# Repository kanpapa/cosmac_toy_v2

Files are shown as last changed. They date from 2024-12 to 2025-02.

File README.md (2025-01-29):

# COSMAC Toy Computer Version 2

[COSMAC Toy Computer](https://github.com/kanpapa/cosmac_toy)は「トラ技別冊 つくるシリーズ7 手作りコンピュータ入門」（1981年5月初版）を参考にして、COSMAC CPUボードやプログラムローダーや実験回路をコンパクトな基板にまとめて製作したものです。  
ROMは搭載されておらず、トグルスイッチでRAMにプログラムを書き込んで実行できます。  
16進キーボードを使ったことはあるけど、トグルスイッチを使ってプログラムを動かしてみたいという方の願いを叶えようという思いで作られたシンプルなボードです。モニタプログラムなどの助けを借りずに、トグルスイッチでメモリを直接書き換えてプログラムを実行するといった一連の操作を体験できます。

最初に製作したCOSMAC TOYは1980年代の当時の環境に近づけるべく可能な限り書籍を忠実に再現することを第一に製作しましたので、やや入手が容易ではないパーツも含まれていました。  
このため、実機を使って[COSMACマイコン](https://kanpapa.com/cosmac/cosmac-cpu)の基本的な動きとトグルスイッチによるブートストラップを容易に体験いただけるようにVersion 2として見直しを行いました。

さらに高度なプログラミングを行いたい場合は、モニタが搭載された[SBC1802](https://vintagechips.wordpress.com/2021/04/13/sbc1802fixed/)や[MemberShip Card](https://www.sunrise-ev.com/1802.htm)などの利用をおすすめします。

## Version 2での変更点

* CPUボードとローダーボードを1枚の基板にまとめ、さらに製作を容易にしました。
* メモリを書き込み禁止にするトグルスイッチを追加することで、メモリ内容の読み出しや正しく手順を踏めばメモリの修正も行えるようになりました。
* 600milのS-RAMを使用できるようにしました。これにより600milの6264ALPやDIP変換基板に実装したフラットパッケージのS-RAMも使用できます。
* COSMAC CPUの全ピンにアクセスできるようにピンソケット用のパターンを併設しました。
* Q出力がLEDでモニタできるようになりました。基板単体でQ出力の確認ができます。
* COSMAC CPUとS-RAMを除きすべて秋月電子さんで購入できるパーツとしました。
* USB-C電源コネクタを追加しました。(Rev.0.3)
* 入力トグルスイッチと出力LEDにおいて上位4ビットと下位4ビットの間隔を少し空けました。(Rev.0.3)

## スペック

* CPU: COSMAC CDP1802
* RAM: 256byte
* ROM: 無し
* CLOCK: 約400kHz
* I/O: バスLED, Q-LED, バス設定トグルスイッチ, モード設定トグルスイッチ
* 電源: 5V 標準DCジャック(センタープラス)、USB-C電源(Rev.0.3)
* メモリバックアップバッテリー: CR2032 3V
* サイズ: 95mmX72mm
* 重さ: 約89g（全パーツ実装時）

## 外観
Rev.0.3  
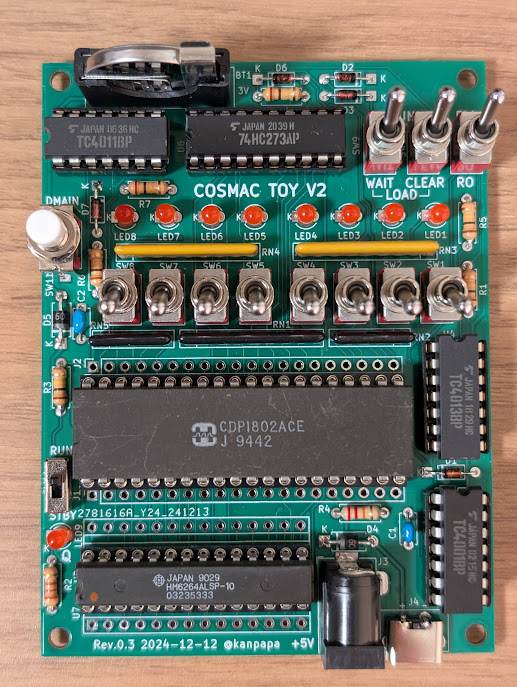
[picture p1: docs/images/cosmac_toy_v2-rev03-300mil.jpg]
rev03
  
[Rev.0.2](/docs/images/cosmac_toy_v2-rev02-600mil.jpg)  
[Rev.0.1](/docs/images/cosmac_toy_v2-rev01-prototype.jpg)  

## 特徴

* 入手が容易なパーツを使い、回路を極力簡素化することで必要なパーツ数を減らしています。専用基板も表面実装パーツは使用せずに製作しやすくしています。
* トグルスイッチで直接メモリに書き込むため、ROMライタなどの開発ツールは不要です。
* COSMAC CPUの全ピンにアクセスできるようにピンソケットを併設しています。CPUバスやQ出力やEF1~4入力などのアクセスはここから行ってください。
* メモリは6264を使用していますが、実際に使えるのは256バイトだけです。これはトグルスイッチで正確に手入力できるのは256バイトが限界と思われるため、アドレスバスを簡略化したためです。
* S-RAMは簡易的なバッテリバックアップが行えます。SW11をSTBYにするとメモリをスタンバイ状態にし、バッテリーで内容が保持されます。
* 8つのLEDはバスの信号をラッチしてバスの状態を表示することができます。
* 右上の3つのトグルスイッチで、CPUの動作モードを設定したあとに、DMA INにつながっているプッシュスイッチを押すことで、トグルスイッチで設定した値をメモリに書き込むことができます。ROにすることでメモリに書き込まずメモリの状態を確認することもできます。
* トグルスイッチはバスの信号を直接0/1に設定します。通常はバスバッファを介しますが、シンプルな回路にするために省略しています。
* Q出力はLEDが接続されています。  
* COSMAC CPUのクロックはCR発振なのでCRの値を変えることで周波数を調整できます。
* 本基板のサイズは秋月電子のB基板に合わせました。

## 基本的な操作方法

* [Quick start guide](/docs/cosmac_toy_v2_quick_start_guide.pdf)も合わせてご覧ください。

    UP    トグルスイッチを上側に倒します  
    DOWN  トグルスイッチを下側に倒します  
     ↓  　トグルスイッチの状態をそのまま維持します。（変更しない）  
     ー   トグルスイッチの状態は任意です。（上側でも下側でも良い）  

1. メモリ書き込み

    |Step|SW9|SW10|SW12|操作内容|
    |---|----|---|----|----|
    |1	|UP|DOWN|-|CPUを初期状態(P, X, R(0)を0)にする(RESETモード)|	
    |2	|↓|↓|UP|メモリ書き込み許可|
    |3	|DOWN|↓|↓|メモリロード状態にする(LOADモード)|
    |4	|| | |トグルスイッチでメモリに書き込む値を設定→DMAINを押す（これを繰り返す） |

1. メモリ読み出し
    |Step|SW9|SW10|SW12|操作内容|
    |---|---|----|----|----|
    |1	|UP|DOWN|-|CPUを初期状態にする(RESETモード)|
    |2  |↓|↓|DOWN|メモリ書き込み禁止|
	|3  |DOWN|↓|↓|メモリロード状態にする(LOADモード)|	
	|4  | | | |DMAINボタンを押すとメモリの内容が表示される（これを繰り返す）|		

1. プログラム実行
    |Step|SW9|SW10|SW12|操作内容|
    |---|----|---|----|----|
    |1|UP|DOWN|-|CPUを初期状態にする(RESETモード)|
    |2|↓|↓|UP|メモリ書き込み許可(メモリに書き込む処理があるプログラムの場合)|	
	|3|↓|UP|↓|プログラム実行状態にする(RUNモード)|

1. プログラム一時停止
    |Step|SW9|SW10|SW12|操作内容|
    |---|---|---|---|---|
	|1|DOWN|UP|-|プログラム実行を一時停止する(PAUSEモード)|
	|2|UP|↓|- |プログラム実行状態にする(RUNモード)|

1. メモリバックアップ状態〜通常状態への切替
    |Step|SW9|SW10|SW12|SW11|操作内容|
    |---|---|---|---|---|---|
    |1|DOWN|UP|-|RUN|プログラムを一時停止する(PAUSEモード)|
    |2|↓|↓|DOWN|↓|メモリ書き込み禁止|
    |3|↓|↓|↓|STBY|RAMをスタンバイモードにする|
    |4|↓|↓|↓|↓|電源を切断|
    |5|DOWN|UP|DOWN|STBY|PAUSEモード+メモリ書き込み禁止になっていることを確認|
    |6|↓|↓|↓|↓|電源を投入|
    |7|↓|↓|↓|RUN|RAMをノーマルモードにする|

※メモリバックアップを行わない場合はリチウム電池は抜いておいてください。電源が供給されない状態でSW11がRUNのままだと放電してしまいます。

## ハードウェア

- [回路図](/schematics/)
- [部品表](/bom/)
- [KiCadデータ](/kicad/)
- [ガーバーデータ](/gerber/)
- [組み立て手順例](/docs/Assembly_instruction/)
- 組み立て時の注意事項  
    - 部品表に記載されているLEDと異なるLEDを使用する場合は、RN3 2.2KΩの集合抵抗では眩しすぎる場合もありますので、丸ピンソケットを利用して集合抵抗を交換調整できるようにしておくことをお勧めします。

## ソフトウェア
 
- [サンプルアプリケーション](/programs/)

## 補足情報

- [COSMAC研究会](https://kanpapa.com/cosmac/)に関連記事をまとめています。

## 参考・引用文献

- トランジスタ技術別冊 つくるシリーズ７ 手作りコンピュータ入門 CQ出版社, 1981
- [KiCad 8 入門実習テキスト『KiCad Basics for 8.0』Kosaka.Lab.出版掛](https://kosakalab.booth.pm/items/5554691)
- [intersil CDP1802AC/3データシート](https://www.renesas.com/jp/ja/www/doc/datasheet/cdp1802ac-3.pdf)
- [SB-Assembler](https://www.sbprojects.net/sbasm/)
- [COSMAC ELF - RCA CDP1802 Computing](http://www.cosmacelf.com/)
- [Compute II Issue 3: The 1802 Instruction Set](https://www.atarimagazines.com/computeii/issue3/page52.php)
- [The 1802 Membership Card](http://www.sunrise-ev.com/1802.htm)

## 利用上の注意

本サイトに掲載している回路、技術、プログラムなどは無保証です。  
これらの利用によって発生したトラブルには責任を負いかねます。自己責任にてご利用ください。  
KiCADデータおよびガーバーデータはCC BY-SA 4.0 (Copyright (C) 2024 Kazuhiro Ouchi)です。  
サンプルプログラムはMITライセンスです。

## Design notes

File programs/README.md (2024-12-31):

# COSMAC TOY Computer Sample program

サンプルプログラムのアセンブラソースとSB-Assemblerでアセンブルしたリストです。  
こちらを参考にしてプログラムの入力や改良をしてください。

## サンプルプログラム

* [パルス信号を作る](01_osc1/README.md)
    * [01_osc1](01_osc1) - 動作確認用。Q出力の0,1を繰り返します。Q出力のLEDは超高速点滅なので点灯したままに見えます。オシロであれば信号を確認できます。
* [カウンタプログラム1](02_counter1/README.md)
    * [02_counter1](02_counter1) - 加算しているカウンタの値をLEDに表示し続けます。速すぎて最上位ビットのLEDがチラチラするだけで他のLEDは点灯状態に見えます。
* [カウンタプログラム2](03_counter2/README.md)
    * [03_counter2](03_counter2) - 加算しているカウンタの値をLEDに表示し続ける低速表示版です。これぐらいでようやくカウントの様子が見えます。
* [加算プログラム](04_add1/README.md)
    * [04_add1](04_add1) - トグルスイッチで設定した値に6を加算した数値をLEDに表示します。
* [押しボタンスイッチでQ出力を制御](05_sw1/README.md)
    * [05_sw1](05_sw1) - EF1に接続したスイッチを押すとQ-LEDが消灯し、離すとQ-LEDが点灯します。
* [Q LEDを点滅させる](06_blink1/README.md)
    * [06_blink1](06_blink1) - Q LEDが一定時間間隔で点滅します。いわゆるLチカです。
* [POVを試してみる](07_pov1/README.md)
    * [07_pov](07_pov1) - POV(Persistent Of Vision)によるメッセージ表示です。もう少しチューニングできると思います。
* [シリアルバイナリローダー](08_binloader1/README.md)
    * [08_binloader1](08_binloader1) - USBシリアル変換モジュールを接続して入力されたシリアルデータをLEDに表示しながらメモリに書き込みます。

## Requirement

This source file can be assembled using SB-Assembler 3.
* [SB-Projects - SB-Assembler](https://www.sbprojects.net/sbasm/)

## License

This software is released under the [MIT license](https://en.wikipedia.org/wiki/MIT_License).

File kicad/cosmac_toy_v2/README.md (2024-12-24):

# COSMAC TOY V2 KiCad project

COSMAC TOY V2の基板のKiCADデータです。

以下に公開されているフットプリントを使用させていただきました。

* USB Type-Cコネクター 電源供給用	A295-CTRPB-1:A295-CTRPB-1  
https://github.com/21km43/A295-CTRPB-1_KiCAD  
Copyright (c) 2023 Koki Mizumoto

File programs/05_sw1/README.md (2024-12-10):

# 押しボタンスイッチでQ出力を制御

## 概要
EF1～EF4（4フラグ）の使用例です。  
EF1～EF4入力により、外部機器からのステータス情報をプロセッサに転送できます。
これらの入力レベルは、条件分岐命令でテストできます。

ここではEF1端子に押しボタンスイッチを接続し、スイッチを押した場合はEF1端子がHIGH、押していないときはEF1端子がLOWとなるようにしています。  
プログラムでEF1端子がHIGH(=5V)なのかLOW(=0V)なのかで処理を分岐し、Q出力を1にセットするもしくは0にリセットする処理を行います。

## 使用する命令

|INSTRUCTION|MNEMONIC|OP CODE|OPERATION|
|---|---|---|---|
|SHORT BRANCH IF EF1 = 1 (EF1 = VSS)|B1|34|IF EF1 = 1, M(R(P)) → R(P).0, ELSE R(P) + 1 → R(P)|
|RESET Q|REQ|7A|0 → Q|
|SHORT BRANCH|BR|30|M(R(P)) → R(P).0|
|SET Q|SEQ|7B|1 → Q|

## サンプルコード

```
0000-34 05    START:  B1      L1                  ; ~EF1 = 1(VSS) だったら L1にジャンプ
0002-7A               REQ                         ; Q出力を0にする(LED消灯)
0003-30 00            BR      START               ; 0000番地にジャンプ
0005-7B       L1:     SEQ                         ; Q出力を1にする(LED点灯)
0006-30 00            BR      START               ; 0000番地にジャンプ
```

## 回路図

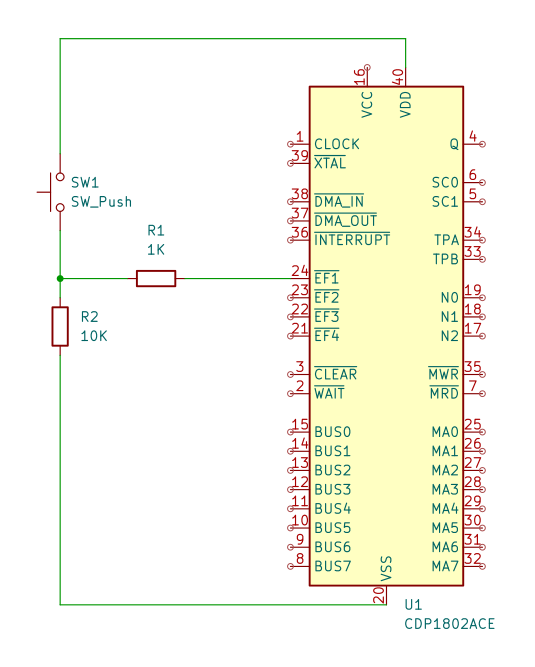
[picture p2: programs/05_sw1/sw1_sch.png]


## 実行結果
手元にあったDFROBOT社の[Gravity: Digital Push Button (Yellow)](https://www.dfrobot.com/product-73.html)を使用しています。  
画像をクリックすると動画が再生されます。

sw1 video (https://www.youtube.com/watch?v=XKFlwYPNNAE)

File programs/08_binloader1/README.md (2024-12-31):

# Serial Binary loader for COSMAC TOY V2

[プログラム05 押しボタンスイッチ](/programs/05_sw1/README.md)ではEF1端子の入力信号を読み取ってQ-LEDを点灯させました。  
これを応用してシリアルデータ信号をEF端子に入力することで、データ転送ができるのではないでしょうか。  
実際にそのような使いかたを行って、シリアル通信を使ってバイナリデータをメモリにロードすることができます。

オリジナルは1802 MemberShip Card用のプログラムですが、これをCOSMAC TOY V2でも動作するように修正しました。

* 参考サイト
    [Serial Binary loader for 1802 Membership Card](https://www.retrotechnology.com/memship/mship_binloader.html)
* 参考ソース
    [Here's Jonathan Mordosky's original binary loader code](https://www.retrotechnology.com/memship/binldr_m.asm)

## 回路図

COSMAC TOY V2とUSBシリアル変換モジュールを接続しPCと接続します。IOの電圧は5Vのものを使用してください。  
私は秋月電子の[FT-232RQ USBシリアル変換モジュール](https://akizukidenshi.com/catalog/g/g111007/)を使用しました。

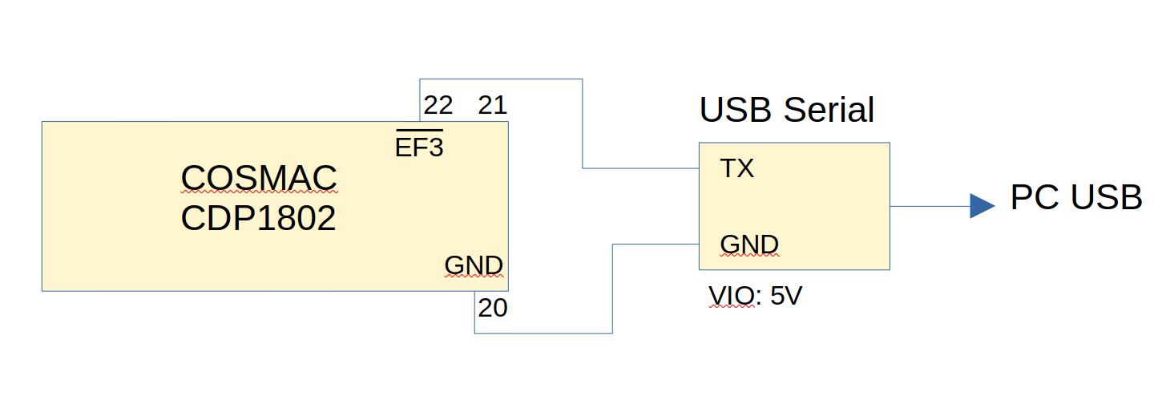
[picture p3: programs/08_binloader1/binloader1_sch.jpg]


実際にUSBシリアル変換モジュールに接続している様子です。

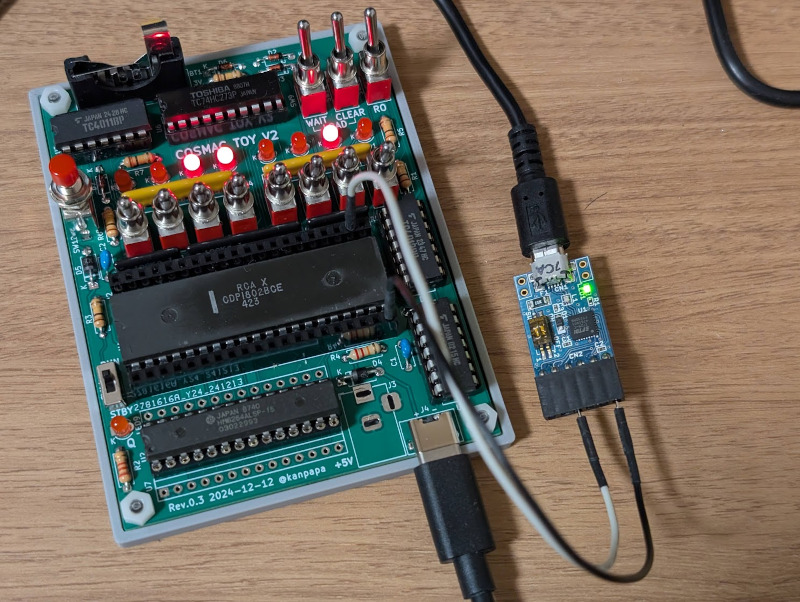
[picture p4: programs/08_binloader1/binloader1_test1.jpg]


## 実際のシリアル信号

上記の回路図でEF3端子にどのような信号が流れるのかをロジックアナライザで確認しました。このシリアルデータはスペースコード(0x20)です。



最初の緑色の点がスタートビットです。  
その後、データの下位ビットから上位ビットに向けてデータのビットが８個並びます。  
最後の赤色の点がストップビットです。  
プログラムではこの信号をEF3端子で読み取って、ソフトウェアでシリアルデータをデコードしてメモリにストアします。

## ソースコード

修正したソースコードのアセンブル結果は以下のようになります。シリアル信号を見ながら追ってみてください。  
COSMAC TOY V2用に修正した箇所は以下の通りです。
- メモリが0000-00FFまでしか使えないのでロードアドレスは0040-としました。
- オリジナルのソースコードでは信号が反転していたので、EF3のチェック部分を反転しました。（B3をBN3に、BN3をB3に入れ替えています。）

最初にスペースコードを入力することで、1ビットの時間をカウントしています。このカウント値を使用したタイミングで読み取ることでシリアルデータのビットに追従します。COSMAC TOY V2はクロックが400KHzなので高速通信は難しいですが、300bpsは問題なく動作しました。

※ソースコードは暫定版です。コメントなど整理した上で更新予定です。
```
SB-Cross Assembler version 3.03.10
Please visit www.sbprojects.net for a complete description.

Assembling....

Pass one
Loaded 1802 overlay version 3.01.01

Pass two
0000-                  1        ; 1802 Membership Card .bin loader by Jonathan Mordosky
0000-                  2        ; Edited by Lee Hart Oct 29 2015, JOnathan Mordosky Nov 3 2015
0000-                  3        ;
0000-                  4        ; first, here is the original by Jonathan Mordosky in cosmacelf Oct 2015
0000-                  5        ; Loads binary file starting at address XX00, Where XX is any page in memory above 00
0000-                  6        ; For 1802 Membership Card, serial port configured as Normal (not inverting)
0000-                  7        ; Tested at 300 baud 8N1. Should work at slightly higher baud rates
0000-                  8        ;
0000-                  9        ; To Use: Toggle in program as usual.
0000-                 10        ; Start up and configure communications program on host computer.
0000-                 11        ; On 1802MC, make sure write protect is off. Flip switch to Clear, then Run.
0000-                 12        ; Hit <Space> exactly once on host computer, watching that the output LEDs do not change.
0000-                 13        ; On newer revision boards, the green LED will blink as the space character is received.
0000-                 14        ; Send BIN file as ASCII from host computer. Make sure program settings don't strip the 8th bit.
0000-                 15        ; Output LEDs should now change and show the data as it is received.
0000-                 16        ;
0000-                 17        ; When blinking stops, verify that the LEDs match the last byte of the program.
0000-                 18        ; Toggle in a long jump instruction to start of program (0xC0 0xXX 0x00) and run.
0000-                 19        ; If unsuccessful, check com settings and try again.
0000-                 20
0000-                 21        ; Binary loader for COSMAC TOY V2 by Kazuhiro Ouchi
0000-                 22        ; Edited by Kazuhiro Ouchi Dec 31 2024
0000-                 23        ; This source program can be assembled with the SB assembler.
0000-                 24
0000-                 25        ; hex listing for COSMAC TOY V2
0000-                 26
0000-                 27        ;0000   F8 00 B2 F8 40 A2 E2 F8
0000-                 28        ;0008   00 3E 09 36 0B FC 01 3E
0000-                 29        ;0010   0D FF 04 B3 36 14 F8 09
0000-                 30        ;0018   A3 3E 19 93 F6 38 93 FF
0000-                 31        ;0020   01 3A 1F 02 F6 36 29 F9
0000-                 32        ;0028   80 52 23 83 3A 1E 61 30
0000-                 33        ;0030   14
0000-                 34
0000-                 35                .CR 1802
0000-                 36                .OR 0000H       ;initialization　　　　　　　　 初期化
0000-                 37        Page    .eq     00      ; desired page destination      バイナリをロードするページ先。COSMAC TOYは256byteメモリなので00で良い
0000-                 38        ;
0000-F8 00            39 (   2)         LDI Page        ;Set destination starting address   デスティネーション開始アドレスの設定
0002-B2               40 (   2)         PHI 2           ;R2 points to destination           R2 はデスティネーションを指す。
0003-                 41        ;       GHI 0           ;  LSB of destination is 00
0003-F8 40            42 (   2)         LDI $40         ;  LSB of destination is 40  COSMAC TOYの場合はデスティネーションの下位バイトは40とする。
0005-A2               43 (   2)         PLO 2           ;  (assumes this program is at 00XX)  ロードするプログラムは00XXにあると仮定する。
0006-E2               44 (   2)         SEX 2
0007-F8 00            45 (   2)         LDI 0           ; Dレジスタを$40にしてしまったので0を設定しておく。(Timeで使うから)
0009-                 46
0009-3E 09            47 (   2) LoopA   BN3 LoopA       ;スタートビットを待つ。EF3がHIGHの場合はループ。B3がLOWになったら次のステップへ
000B-                 48
000B-36 0B            49 (   2) LoopB   B3 LoopB        ;ASCIIコードのスペースのD5=1のデータビット(EF3がHIGH)を待つ。（データはLSBファーストで送信される）
000D-                 50                                                ;time Data bit D5
000D-                 51                                                ;  Dレジスタは0に初期化済
000D-FC 01            52 (   2) Time    ADI 1           ;  D=D+1 for each loop   Dを1加算するループ
000F-3E 0D            53 (   2)         BN3 Time        ;  ...until end of bit   データビット終了(EF3=LOWになる)までループで加算し続ける。データビットが終了したら次のステップへ
0011-                 54                                        ;each loop is 2 instructions,
0011-                 55                                        ;so Delay x 2 = number of instructions per bit
0011-FF 04            56 (   2)         SMI 4           ;Subtract 4 extra instructions
0013-B3               57 (   2)         PHI 3           ;Store Delay Constant in R3.1
0014-                 58
0014-                 59        ;       so (Delay+4) x 2 = # of instructions in one bit time
0014-                 60
0014-                 61                                                ;OK, we're ready to receive data
0014-36 14            62 (   2) Main    B3 Main         ;ストップビット(EF3=HIGH)を待つ
0016-F8 09            63 (   2)         LDI 9           ;R3.0 = #bits = 9
0018-A3               64 (   2)         PLO 3
0019-3E 19            65 (   2) LoopC   BN3 LoopC       ;スタートビット(EF3=LOW)を待つ
001B-93               66 (   2)         GHI 3           ;Delay 1/2 bit time
001C-F6               67 (   2)         SHR             ;  to move to middle of bit
001D-38               68 (   2)         SKP             ;
001E-93               69 (   2) NextBit GHI 3           ;Delay one bit time
001F-                 70
001F-FF 01            71 (   2) Delay   SMI 001H
0021-3A 1F            72 (   2)         BNZ Delay
0023-                 73
0023-02               74 (   2)         LDN 2           ;Get bits received so far...
0024-F6               75 (   2)         SHR                 ;  Shift right, and set most.sig.bit=0
0025-36 29            76 (   2)         B3 Zero             ;  if serial input=1 (i.e. EF3 pin is low)　シリアルデータビットが0（EF3がLow）の場合は分岐する
0027-F9 80            77 (   2)         ORI 080H        ;    then set most.sig.bit=1 シリアルデータビットが1の場合はORでビットを立てる
0029-52               78 (   2) Zero    STR 2           ;Store Data  R2は転送先アドレスを指す。そこにデータをストアする
002A-23               79 (   2)         DEC 3           ;Count out bits　処理したビットをカウント
002B-83               80 (   2)         GLO 3
002C-3A 1E            81 (   2)         BNZ NextBit     ;Loop until byte Finished
002E-                 82        ;       OUT 4           ;Show Data and INC Pointer
002E-61               83 (   2)         OUT 1           ;受信したデータをLEDに表示。COSMAC TOY V2の場合はOUT1なので変更しました。
002F-30 14            84 (   2)         BR  Main        ;Get next byte
0031-                 85
0031-                 86                .EN

0 Errors found during assembly.
0 Warnings found during assembly.
```

## 実行方法
1. 以下のシリアルローダープログラムをトグルスイッチで入力します。49バイトですので頑張って入力しましょう。
    ```
    0000   F8 00 B2 F8 40 A2 E2 F8
    0008   00 3E 09 36 0B FC 01 3E
    0010   0D FF 04 B3 36 14 F8 09
    0018   A3 3E 19 93 F6 38 93 FF
    0020   01 3A 1F 02 F6 36 29 F9
    0028   80 52 23 83 3A 1E 61 30
    0030   14
    ```
1. USBシリアル変換モジュールをCOSMAC TOY V2に接続します。
1. リセットしてシリアルローダープログラムを実行します。メモリは書き込み可能な状態にしてください。
1. PCでシリアルターミナルを起動します。通信速度は300bpsで、データ形式は8N1（データ8ビット、ストップ１ビット、パリティ無し）に設定してください。
1. シリアルターミナルから最初にスペースキーを１回押下します。これでプログラムが通信速度を設定します。
1. その後バイナリデータをPCのシリアルターミナルから送信すると、その内容が0040以降に書き込まれます。
1. バイナリデータを送信し終わったら、最後のデータの内容とLEDの表示が一致しているはずです。ここでプログラムを停止してください。(WAITスイッチを上側に倒す)
1. メモリの書き込みを禁止して、LOADモードにして、0040以降にアップロードしたバイナリデータが書かれているかを確認してください。

バイナリデータの代わりに、キーボードから文字を入力すればそのASCIIコードが0040以降に書き込まれます。文字を入力するたびにLEDがその文字のASCIIコードに変化することが確認できます。

## 実行結果
PCのシリアルターミナルで数字のキーを押すとASCIIコードの0x30-0x39がLEDに表示されます。  
クリックすると動画が表示されます。  
binloader1-1 video (https://www.youtube.com/watch?v=f7oefC-dY0M)

PCのシリアルターミナルで適当にキーボードを入力すると、入力した文字のASCIIコードがLEDに表示されます。  
クリックすると動画が表示されます。  
 binloader1-2 video (https://www.youtube.com/watch?v=1_WPMiToYoo)

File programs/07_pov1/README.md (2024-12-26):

# POVを試してみる

## 概要
いわゆるPOV(Persistent Of Vision)です。目の残像を利用してLEDでメッセージを表示するものです。　  
COSMAC TOY V2では8個のLEDが使えますので、このLEDにビットマップデータの1列毎に一定時間表示するようにしておきます。この状態でCOSMAC TOY V2基板を横に振ることでうまくいけばメッセージが表示されているように見えます。  
個人差や照明環境もありますので、うまく見えない場合は7行目のLDI 60の値を調整してください。  
表示するビットマップデータを入れ替えることもできます。ビットマップのデータ数を4行目のLDI 27で設定していますので、ビットマップデータの長さに合わせて調整してください。  
ビットマップデータの値でLEDを表示するためにOUT 1命令を使用していますが、この命令は自動的にインデックスレジスタを加算してくれますので、今回のような連続したデータの出力は容易に行えることがわかります。

## 使用する命令
|INSTRUCTION|MNEMONIC|OP CODE|OPERATION|
|---|---|---|---|
|LOAD IMMEDIATE|LDI|F8|M(R(P)) → D; R(P) + 1 → R(P)|
|PUT LOW REG N|PLO|AN|D → R(N).0|
|SET X|SEX|EN|N→X|
|OUTPUT 1|OUT 1|61|M(R(X)) → BUS; R(X) + 1 → R(X); N LINES = 1|
|DECREMENT REG N|DEC|2N|R(N) - 1 → R(N)|
|GET LOW REG N|GLO|8N|R(N).0 → D|
|SHORT BRANCH IF D NOT 0|BNZ|3A|IF D NOT 0, M(R(P)) → R(P).0, ELSE R(P) + 1 → R(P)|
|SHORT BRANCH|BR|30|M(R(P)) → R(P).0|

## サンプルコード

```
0000-                  1        *
0000-                  2        * POV program 1 for COSMAC TOY V2
0000-                  3        * SB-Assembler
0000-                  4        *
0000-                  5                .CR     1802    ;To load the 1802 cross overlay
0000-                  6                .OR     $0000
0000-                  7        *
0000-                  8        * R3 BITMAPデータを指すインデックスレジスタ
0000-                  9        * R4 BITMAPデータの個数カウンタ
0000-                 10        * R5 ウェイトカウンタ
0000-                 11        *
0000-F8 15            12 (   2) START   LDI     #BITMAP ; DレジスタにBITMAPデータの先頭アドレスを設定
0002-A3               13 (   2)         PLO     3       ; R3にBITMAPのアドレスを設定
0003-E3               14 (   2)         SEX     3       ; R3をインデックスレジスタに設定
0004-F8 1B            15 (   2)         LDI     27      ; DレジスタにBITMAPデータの個数である27を設定する
0006-A4               16 (   2)         PLO     4       ; R4にBITMAPデータカウンタの初期値を設定する
0007-61               17 (   2) LOOP1   OUT     1       ; BITMAPのデータでLEDを表示する。R3は自動インクリメントされる。BUS <- M(R(3)); R(3)++
0008-F8 3C            18 (   2)         LDI     60      ; ウェイトカウンタの初期値←ここは調整要
000A-A5               19 (   2)         PLO     5       ; R5をウェイトカウンタとしてDレジスタから初期値を設定する
000B-25               20 (   2) LOOP2   DEC     5       ; ウェイトカウンタを1減らす。
000C-85               21 (   2)         GLO     5       ; Dレジスタにウェイトカウンタをセット
000D-3A 0B            22 (   2)         BNZ     LOOP2   ; Dレジスタが0でなかったらLOOP2へ
000F-24               23 (   2)         DEC     4       ; BITMAPカウンタを１減らす
0010-84               24 (   2)         GLO     4       ; DレジスタにBITMAPデータカウンタの値をセット
0011-3A 07            25 (   2)         BNZ     LOOP1   ; Dレジスタが0でなかったらLOOP1へ
0013-30 00            26 (   2)         BR      START   ; BITMAPのデータを表示し終えたので、最初から繰り返し
0015-                 27        *
0015-                 28        * BITMAP DATA "HELLO" 27byte
0015-                 29        *
0015-FE               30        BITMAP  .DB     0b11111110      ; H
0016-10               31                .DB     0b00010000
0017-10               32                .DB     0b00010000
0018-10               33                .DB     0b00010000
0019-FE               34                .DB     0b11111110
001A-00               35                .DB     0b00000000
001B-                 36
001B-FE               37                .DB     0b11111110      ; E
001C-92               38                .DB     0b10010010
001D-92               39                .DB     0b10010010
001E-92               40                .DB     0b10010010
001F-00               41                .DB     0b00000000
0020-                 42
0020-FE               43                .DB     0b11111110      ; L
0021-80               44                .DB     0b10000000
0022-80               45                .DB     0b10000000
0023-80               46                .DB     0b10000000
0024-00               47                .DB     0b00000000
0025-                 48
0025-FE               49                .DB     0b11111110      ; L
0026-80               50                .DB     0b10000000
0027-80               51                .DB     0b10000000
0028-80               52                .DB     0b10000000
0029-00               53                .DB     0b00000000
002A-                 54
002A-FE               55                .DB     0b11111110      ; O
002B-82               56                .DB     0b10000010
002C-82               57                .DB     0b10000010
002D-82               58                .DB     0b10000010
002E-FE               59                .DB     0b11111110
002F-00               60                .DB     0b00000000
0030-                 61
0030-                 62                .EN
```

## 実行結果
このプログラムを実行するとLEDがチラチラするだけで、正常に動作しているのかわかりません。  
画像をクリックすると動画が再生されます。  
blink1 video (https://www.youtube.com/watch?v=aNgpml-eRWY)

この状態でCOSMAC TOY V2基板を手に持ち横に振るとかろうじてメッセージが見えます。（心の目で見てください・・・）  
画像をクリックすると動画が再生されます。  
blink1 video (https://www.youtube.com/watch?v=d47GrqhgYpU)

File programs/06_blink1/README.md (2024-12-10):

# Q LEDを点滅させる

## 概要
Q LEDが一定時間間隔で点滅します。いわゆるLチカです。  
最初にアキュームレータである8ビットのDレジスタに$40を設定していますが、この値は点滅間隔の待ち時間のカウンタとして使用されるR4レジスタの上位バイトに代入されます。  
COSMACの汎用レジスタ(R0〜RF)は16bitですが、16bitの値を直接設定することができないため、Dレジスタを介して上位バイト、下位バイトに8bitずつ値を設定する必要があります。なおリセット直後は各レジスタの値は0となっていますので、R4の下位バイトの0設定は省略しています。  
R4レジスタを1減算したあとに、0になったかを確認していますが、この確認もDレジスタを使う必要があり、上位バイト、下位バイトをそれぞれ確認しています。  

このように何をやるにしてもこのDレジスタを経由して行うことが多いです。

## 使用する命令
|INSTRUCTION|MNEMONIC|OP CODE|OPERATION|
|---|---|---|---|
|LOAD IMMEDIATE|LDI|F8|M(R(P)) → D; R(P) + 1 → R(P)|
|PUT HIGH REG N|PHI|BN|D → R(N).1|
|LONG SKIP IF Q = 1|LSQ|CD|IF Q = 1, R(P) + 2 → R(P), ELSE CONTINUE|
|SET Q|SEQ|7B|1 → Q|
|SHORT SKIP|SKP|38|R(P) + 1 → R(P)|
|RESET Q|REQ|7A|0 → Q|
|DECREMENT REG N|DEC|2N|R(N) - 1 → R(N)|
|GET LOW REG N|GLO|8N|R(N).0 → D|
|GET HIGH REG N|GHI|9N|R(N).1 → D|
|SHORT BRANCH IF D NOT 0|BNZ|3A|IF D NOT 0, M(R(P)) → R(P).0, ELSE R(P) + 1 → R(P)|
|SHORT BRANCH|BR|30|M(R(P)) → R(P).0|

## サンプルコード

```
0000-F8 40    START:  LDI     #$40                ; Dレジスタに$40を入れる（点滅間隔のウェイトループ値）
0002-B4               PHI     4                   ; R4の上位バイトにDレジスタの値を代入する
0003-CD               LSQ                         ; Qが1だったら2バイトスキップする
0004-7B               SEQ                         ; Qを1にする
0005-38               SKP                         ; 次の命令を無条件でスキップする
0006-7A               REQ                         ; Qを0にする
0007-24       LOOP1:  DEC     4                   ; R4を1減算する
0008-84               GLO     4                   ; DレジスタにR4の下位バイトを代入する
0009-3A 07            BNZ     LOOP1               ; Dレジスタが0でなければLOOP1にジャンプ
000B-94               GHI     4                   ; DレジスタにR4の上位バイトを代入する
000C-3A 07            BNZ     LOOP1               ; Dレジスタが0でなければLOOP1にジャンプ
000E-30 00            BR      START               ; 0番地から繰り返し
```

## 実行結果
Q-LEDの点滅ができました。  
画像をクリックすると動画が再生されます。

blink1 video (https://www.youtube.com/watch?v=glT6MU6y57Q)

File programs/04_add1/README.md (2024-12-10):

# 加算プログラム

## 概要
トグルスイッチで設定した値に6を加算した数値をLEDに表示します。

## 使用する命令
|INSTRUCTION|MNEMONIC|OP CODE|OPERATION|
|---|---|---|---|
|LOAD IMMEDIATE|LDI|F8|M(R(P)) → D; R(P) + 1 → R(P)|
|PUT LOW REG N|PLO|AN|D → R(N).0|
|SET X|SEX|EN|N→X|
|INPUT 2|INP 2|6A|BUS → M(R(X)); BUS → D; N LINES = 2|
|ADD|ADD|F4|M(R(X)) + D → DF, D|
|STORE VIA N|STR|5N|D → M(R(N))|
|OUTPUT 1|OUT 1|61|M(R(X)) → BUS; R(X) + 1 → R(X); N LINES = 1|
|DECREMENT REG N|DEC|2N|R(N) - 1 → R(N)|
|SHORT BRANCH|BR|30|M(R(P)) → R(P).0|

## サンプルプログラム

```
0000-F8 0D  START LDI #IOR    IOレジスタのメモリアドレスをDレジスタに代入する
0002-A5           PLO 5       Dレジスタの内容をR5レジスタの下位8ビットに代入する。（R5レジスタはIOレジスタのメモリアドレスになる。）
0003-E5           SEX 5       5をインデックスレジスタXに代入する。
0004-6A     LOOP1 INP 2       BUSの内容をR(X)レジスタ（ここではR5レジスタ）が示すメモリに代入する。
0005-F8 06        LDI #$06    加算する値である6をDレジスタに代入する。
0007-F4           ADD         R(X)レジスタ（ここではR5レジスタ）が示すメモリの内容とDレジスタを加算する。
0008-55           STR 5       Dレジスタの内容をR5レジスタが示すメモリに代入する。
0009-61           OUT 1       R(X)レジスタ（ここではR5レジスタ）が示すメモリの内容をLEDに出力する。
000A-25           DEC 5       OUT命令でR5に1加算されるので、1減算して元に戻す。
000B-30 04        BR LOOP1    LOOP1にジャンプする。
000D-       *
000D-00     IOR   .DB 0       IO Register
```

## 動作確認
* このプログラムを動かして、トグルスイッチを00000000（10進数で0）にするとLEDの値は00000110（10進数で6）になります。
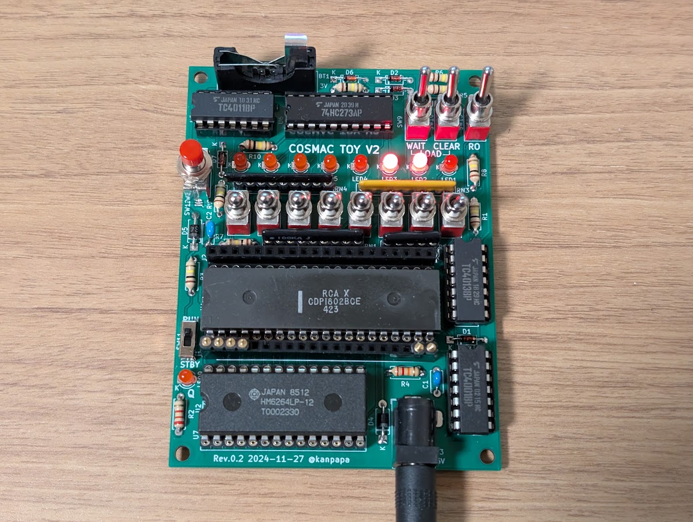
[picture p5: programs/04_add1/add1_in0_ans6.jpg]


* トグルスイッチを00000010（10進数で2）とすると、LEDの値は00001000（10進数で8）になります。
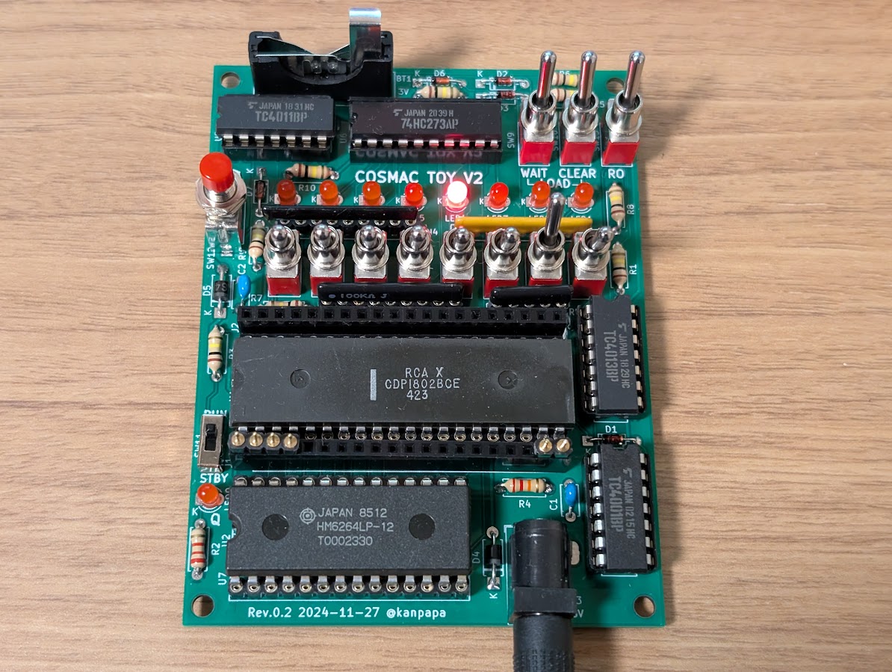
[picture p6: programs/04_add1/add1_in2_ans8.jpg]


* トグルスイッチを00000110（10進数で6）とすると、LEDの値は00001100（10進数で12）になります。
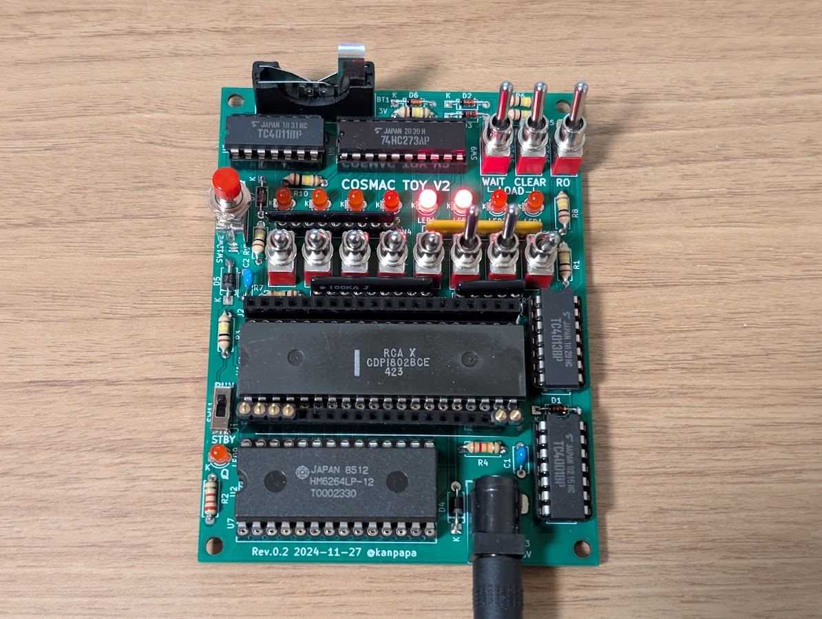
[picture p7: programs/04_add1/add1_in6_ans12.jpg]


* このようにいろいろな数値をトグルスイッチで設定して結果を確認してみてください。

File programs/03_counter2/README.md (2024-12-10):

# カウンタプログラム2

## 概要
R4レジスタをカウントアップしてその値をLEDに表示することを繰り返すものですが、カウンタプログラム1の命令を１つ変更するだけで、R4レジスタの下位8ビットの値をLEDに出力していたものが、上位8ビットの値をLEDに出力するようになります。この結果LEDの表示が256分の1の速度になります。

## 使用する命令
|INSTRUCTION|MNEMONIC|OP CODE|OPERATION|
|---|---|---|---|
|LOAD IMMEDIATE|LDI|F8|M(R(P)) → D; R(P) + 1 → R(P)|
|PUT LOW REG N|PLO|AN|D → R(N).0|
|SET X|SEX|EN|N→X|
|GET HIGH REG N|GHI|9N|R(N).1 → D|
|STORE VIA N|STR|5N|D → M(R(N))|
|OUTPUT 1|OUT 1|61|M(R(X)) → BUS; R(X) + 1 → R(X); N LINES = 1|
|DECREMENT REG N|DEC|2N|R(N) - 1 → R(N)|
|INCREMENT REG N|INC|1N|R(N) + 1 → R(N)|
|SHORT BRANCH|BR|30|M(R(P)) → R(P).0|

## サンプルプログラム
```
0000-F8 31   START LDI #$31    #$31をDレジスタに入れる
0002-A3            PLO 3       Dレジスタの内容をR3レジスタの下位8ビットに入れる
0003-E3            SEX 3       3をインデックスレジスタXに入れる
0004-94      LOOP1 GHI 4       R4レジスタの上位8ビットをDレジスタに入れる
0005-53            STR 3       Dレジスタの内容をR3レジスタが示すメモリに代入する。
0006-61            OUT 1       R(X)（ここではR3）レジスタが示すメモリの内容をBUSに出力する。
0007-23            DEC 3       OUT命令でR3レジスタが1加算されるので、R3レジスタを1減算しておく
0008-14            INC 4       R4を1加算する（カウントアップ）
0009-30 04         BR LOOP1    LOOP1にジャンプする。
```
## 実行結果
カウンタプログラム1に比べてLEDの表示が256分の1の速度になりました。これでカウントしている様子がわかるようになりました。  
画像をクリックすると動画が再生されます。

counter2 video (https://www.youtube.com/watch?v=4HAdMqkbjag)

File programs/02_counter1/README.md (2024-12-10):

# カウンタプログラム1

## 概要
R4レジスタをカウントアップしてその値をLEDに表示することを繰り返すものです。

## 使用する命令
|INSTRUCTION|MNEMONIC|OP CODE|OPERATION|
|---|---|---|---|
|LOAD IMMEDIATE|LDI|F8|M(R(P)) → D; R(P) + 1 → R(P)|
|PUT LOW REG N|PLO|AN|D → R(N).0|
|SET X|SEX|EN|N→X|
|GET LOW REG N|GLO|8N|R(N).0 → D|
|STORE VIA N|STR|5N|D → M(R(N))|
|OUTPUT 1|OUT 1|61|M(R(X)) → BUS; R(X) + 1 → R(X); N LINES = 1|
|DECREMENT REG N|DEC|2N|R(N) - 1 → R(N)|
|INCREMENT REG N|INC|1N|R(N) + 1 → R(N)|
|SHORT BRANCH|BR|30|M(R(P)) → R(P).0|

## サンプルプログラム

```
0000-F8 31   START LDI #$31    #$31をDレジスタに入れる
0002-A3            PLO 3       Dレジスタの内容をR3レジスタの下位8ビットに入れる
0003-E3            SEX 3       3をインデックスレジスタXに入れる
0004-84      LOOP1 GLO 4       R4レジスタの下位8ビットをDレジスタに入れる
0005-53            STR 3       Dレジスタの内容をR3レジスタが示すメモリに代入する。
0006-61            OUT 1       R(X)（ここではR3）レジスタが示すメモリの内容をBUSに出力する。
0007-23            DEC 3       OUT命令でR3レジスタが1加算されるので、R3レジスタを1減算しておく
0008-14            INC 4       R4を1加算する（カウントアップ）
0009-30 04         BR LOOP1    LOOP1にジャンプする。
```

## 実行結果
表示が速すぎて上位ビットのLEDがチラチラするだけで他のLEDは点灯状態です。  
画像をクリックすると動画が再生されます。

counter1 video (https://www.youtube.com/watch?v=xx0XIwDxB0M)

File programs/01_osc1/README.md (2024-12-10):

# パルス信号を作る

## 概要
動作確認用として4バイトのシンプルなプログラムを動かします。CDP1802にはQという端子があり簡単な命令で0/1を出力することができます。

## 使用する命令

|INSTRUCTION|MNEMONIC|OP CODE|OPERATION|
|---|---|---|---|
|SET Q|SEQ|7B|1 → Q|
|RESET Q|REQ|7A|0 → Q|
|SHORT BRANCH|BR|30|M(R(P)) → R(P).0|

## サンプルプログラム

```
0000-7B        START   SEQ             ;Q <- 1
0001-7A                REQ             ;Q <- 0
0002-30 00             BR      START   ;Branch to START
```

## 実行結果
このプログラムを実行するとQ LEDが点灯します。Q端子にオシロスコープを接続すればパルス出力が確認できます。

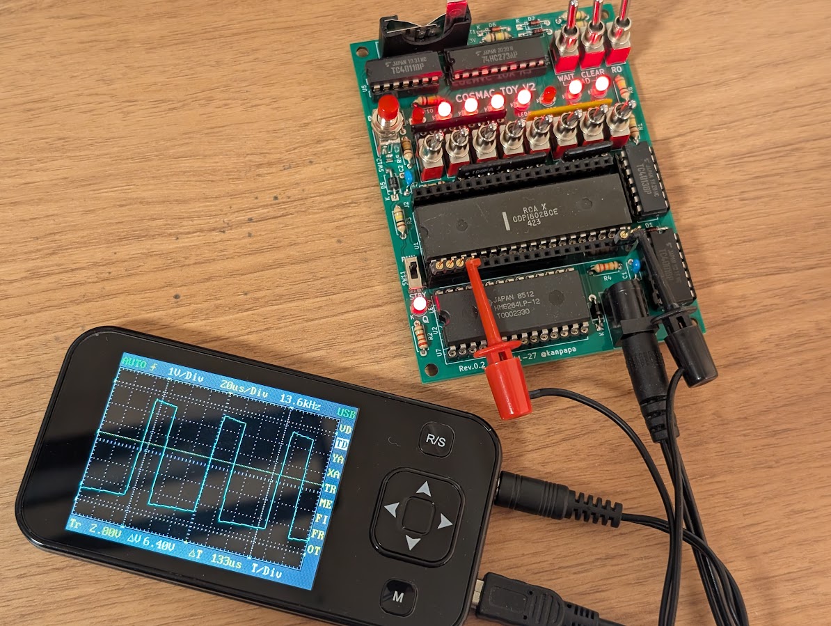
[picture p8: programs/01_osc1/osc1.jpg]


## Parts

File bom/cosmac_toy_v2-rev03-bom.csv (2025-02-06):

Reference | Value | Datasheet | Footprint | Qty | 参考入手先 | 秋月電子販売コード | 単価 | 合計
BT1 | Battery_Cell | ボタン電池基板取付用ホルダー CR2032用(縦型) | Switch_Toggle:CH243-2032CF | 1 | 秋月電子 | 102019 | 80 | 80
C1 | 22p | 積層セラミックコンデンサー 22pF50V C0G 5mm | Capacitor_THT:C_Disc_D4.7mm_W2.5mm_P5.00mm | 1 | 秋月電子 | 108094 | 130 | 13 | 10個入
C2 | 0.1uF | 積層セラミックコンデンサー 0.1μF100V X7R 5mmピッチ | Capacitor_THT:C_Disc_D4.7mm_W2.5mm_P5.00mm | 1 | 秋月電子 | 115927 | 120 | 12 | 10個入
D1,D2,D3,D6,D7 | 1N4148 | 汎用小信号高速スイッチング・ダイオード 1N4148 100V200mA | Diode_THT:D_DO-35_SOD27_P7.62mm_Horizontal | 5 | 秋月電子 | 100941 | 150 | 15 | 50本入り
D4,D5 | 1S4 | 整流用ショットキーダイオード 40V1A 1S4 | Diode_THT:D_A-405_P7.62mm_Horizontal | 2 | 秋月電子 | 100127 | 20 | 40
J1,J2 | Conn_01x20 | ピンソケット (メス) 1×20 (20P) | Connector_PinSocket_2.54mm:PinSocket_1x20_P2.54mm_Vertical | 2 | 秋月電子 | 103077 | 50 | 100 | オプション
J3 | Barrel_Jack_Switch | 2.1mm標準DCジャック(4A) 基板取付用 MJ-179PH | Connector_BarrelJack:BarrelJack_Horizontal | 1 | 秋月電子 | 106568 | 40 | 40 | J3とJ4は使用するものを選択
J4 | USB-C Power | USB Type-Cコネクター 電源供給用 | A295-CTRPB-1:A295-CTRPB-1 | 1 | 秋月電子 | 116895 | 40 | 40 | 電源供給用USB Type-Cコネクター DIP化キット（販売コード: 117123）で使用されているコネクタと同じです。
LED1,LED2,LED3,LED4,LED5,LED6,LED7,LED8,LED9 | LED | 3mm赤色LED 625nm OSR5JA3E34B | LED_THT:LED_D3.0mm | 9 | 秋月電子 | 116588 | 80 | 72 | 10個入
R1,R3,R5,R6,R7,R8 | 100k | カーボン抵抗(炭素皮膜抵抗) 1/4W100kΩ | Resistor_THT:R_Axial_DIN0207_L6.3mm_D2.5mm_P7.62mm_Horizontal | 6 | 秋月電子 | 125104 | 130 | 7.8 | 100本入
R4 | 22k | カーボン抵抗(炭素皮膜抵抗) 1/4W22kΩ | Resistor_THT:R_Axial_DIN0207_L6.3mm_D2.5mm_P7.62mm_Horizontal | 1 | 秋月電子 | 125223 | 130 | 1.3 | 100本入
R2 | 2.2k | カーボン抵抗(炭素皮膜抵抗) 1/4W2.2kΩ | Resistor_THT:R_Axial_DIN0207_L6.3mm_D2.5mm_P7.62mm_Horizontal | 1 | 秋月電子 | 125222 | 100 | 1 | 100本入
RN1 | RN100K-8 | 集合抵抗 8素子 100kΩ | Resistor_THT:R_Array_SIP9 | 1 | 秋月電子 | 114228 | 25 | 25
RN2,RN5 | RN100K-4 | 集合抵抗 4素子 100kΩ | Resistor_THT:R_Array_SIP5 | 2 | 秋月電子 | 114246 | 15 | 30
RN3 | RN2.2K-8 | 集合抵抗 8素子 2.2kΩ | Resistor_THT:R_Array_SIP9 | 1 | 秋月電子 | 113915 | 30 | 30
RN4 | RN10K-8 | 集合抵抗 8素子 10kΩ | Resistor_THT:R_Array_SIP9 | 1 | 秋月電子 | 111910 | 40 | 40
SW1,SW2,SW3,SW4,SW5,SW6,SW7,SW8,SW9,SW10,SW13 | Toggle-SW | 基板用小型3Pトグルスイッチ 1回路2接点 | Switch_Toggle:SW_Toggle_P2.54mm_Vertical | 11 | 秋月電子 | 102399 | 130 | 1430
SW11 | STB-SW | スライドスイッチ 1回路2接点 基板用 | Connector_PinHeader_2.54mm:PinHeader_1x03_P2.54mm_Vertical | 1 | 秋月電子 | 115707 | 20 | 20
SW12 | DMA-IN | 押しボタンスイッチ(赤) | Switch_Toggle:PushSwitch | 1 | 秋月電子 | 104366 | 180 | 180
U1 | CDP1802ACE | http://www.cosmacelf.com/publications/data-sheets/cdp1802.pdf | Package_DIP:DIP-40_W15.24mm_Socket | 1 | オレンジピコショップ |  | 746 | 746 | https://store.shopping.yahoo.co.jp/orangepicoshop/pico-i-140.html
U2 | HM6264ALSP(300mil) |  | Package_DIP:DIP-28_W7.62mm_Socket | 1 | ー |  |  |  | U2とU7はどちらかを選択
U3 | 4001 | 4回路2入力NOR TC4001BP | Package_DIP:DIP-14_W7.62mm | 1 | 秋月電子 | 110911 | 50 | 50
U4 | 4013 | 2回路Dフリップフロップ TC4013BP | Package_DIP:DIP-14_W7.62mm | 1 | 秋月電子 | 114210 | 40 | 40
U5 | 4011 | 4回路2入力NAND TC4011BP | Package_DIP:DIP-14_W7.62mm | 1 | 秋月電子 | 113729 | 40 | 40
U6 | 74HC273 | Dフリップフロップ(D-FF) TC74HC273AP | Package_DIP:DIP-20_W7.62mm | 1 | 秋月電子 | 115412 | 70 | 70
U7 | HM6264ALP(600mil) |  | Package_DIP:DIP-28_W15.24mm_Socket | 1 | 若松通商 |  | 850 | 850 | U2とU7はどちらかを選択
 |  | 専用基板 |  | 1 | JLCPCB |  | 100 | 100 | 5枚で約500円
 |  | 丸ピンICソケット (40P) |  | 1 | 秋月電子 | 100034 | 90 | 90
 |  | 丸ピンICソケット (28P) 300mil |  | 1 | 秋月電子 | 101339 | 70 | 70
 |  | ICソケット (20P) |  | 1 | 秋月電子 | 100009 | 170 | 17 | 10個入
 |  | ICソケット (14P) |  | 3 | 秋月電子 | 100006 | 120 | 36 | 10個入
 |  | 丸ピンIC用ソケット (シングル14P) 1×14 |  | 2 | 秋月電子 | 103470 | 50 | 100 | オプション
 |  |  |  |  |  |  |  | 4386.1
以下64Kメモリが入手できない場合の代替用
 |  | SRAM 64Kb LC3564SM-70 |  | 1 | 秋月電子 | 114234 | 100 | 100 | 在庫限り
 |  | SOP28ピン(1.27mm)DIP変換基板 金フラッシュ |  | 1 | 秋月電子 | 104603 | 70 | 70
 |  | 丸ピンIC用連結ソケット 1×14 MH-1X14-L2： |  | 2 | 秋月電子 | 116982 | 70 | 140
 |  | バッテリバックアップ非対応ですが、256Kメモリも使えるはず。

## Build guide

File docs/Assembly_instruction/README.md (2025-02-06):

# COSMAC TOY V2 組み立て手順例

COSMAC TOY V2の組み立て手順例です。  
基本的には部品の高さが低いものからはんだ付けするとぐらぐらせずに作業しやすいです。  
トグルスイッチの取り付けがやや難しいかもしれません。ゆっくり位置を合わせてください。

- [回路図](/schematics/cosmac_toy_v2-rev03-sch.pdf)
- [部品表](/bom/cosmac_toy_v2-rev03-bom.csv)

1. 基板の目視確認  
基板をじっくり観察し、配線パターンに大きな傷がないかなど表面、裏面を確認してください。
1. ダイオードの取り付け  
ダイオードをはんだ付けします。D4,D5は1S4、その他は1N4148です。極性があるので向きを間違えないようにしてください。
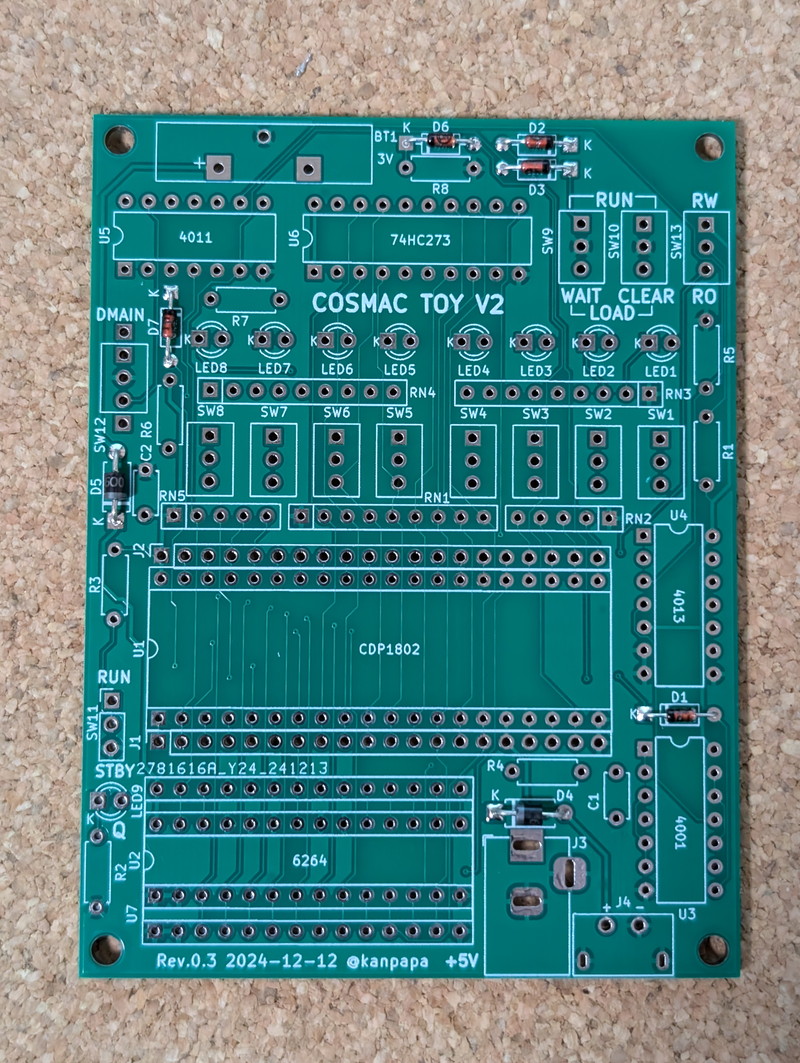
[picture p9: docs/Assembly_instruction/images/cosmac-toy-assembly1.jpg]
 
1. 抵抗の取り付け  
抵抗をはんだ付けします。R4は22KΩ、R2は2.2KΩ、その他は100KΩです。向きを合わせておくときれいに見えます。
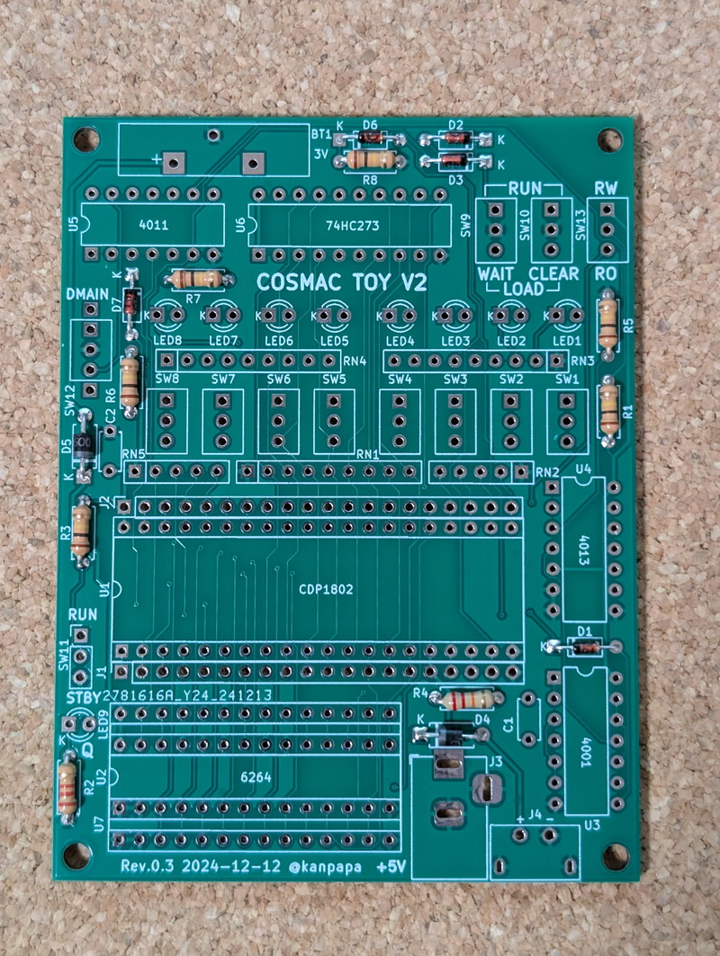
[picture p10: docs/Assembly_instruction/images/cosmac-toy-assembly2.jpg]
 
1. USB-C電源コネクタの取り付け  
USB-C電源コネクタ(J4)を使う場合はここではんだ付けしておきます。
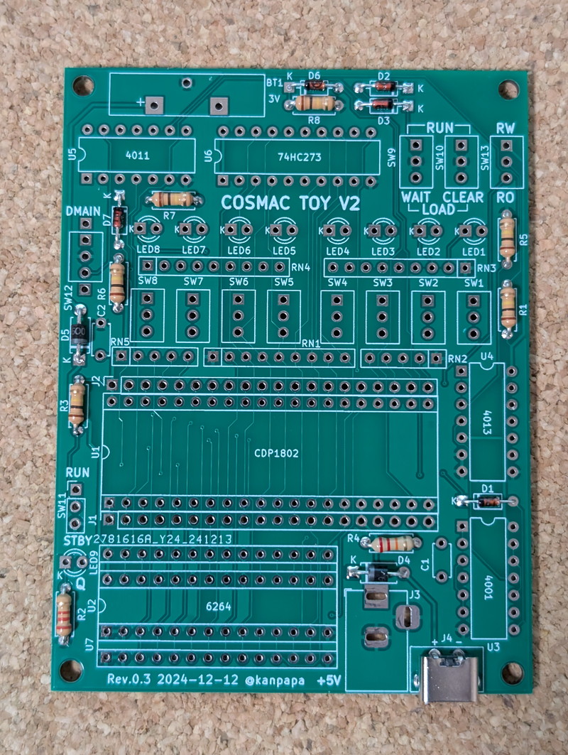
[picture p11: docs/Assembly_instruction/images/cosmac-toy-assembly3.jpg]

1. 丸ピンICソケットの取り付け  
CPU(U1)とS-RAM(U2)のところは丸ピンICソケットをはんだ付けします。向きに注意してください。シルクの切り欠きとソケットの切り欠きを合わせてください。
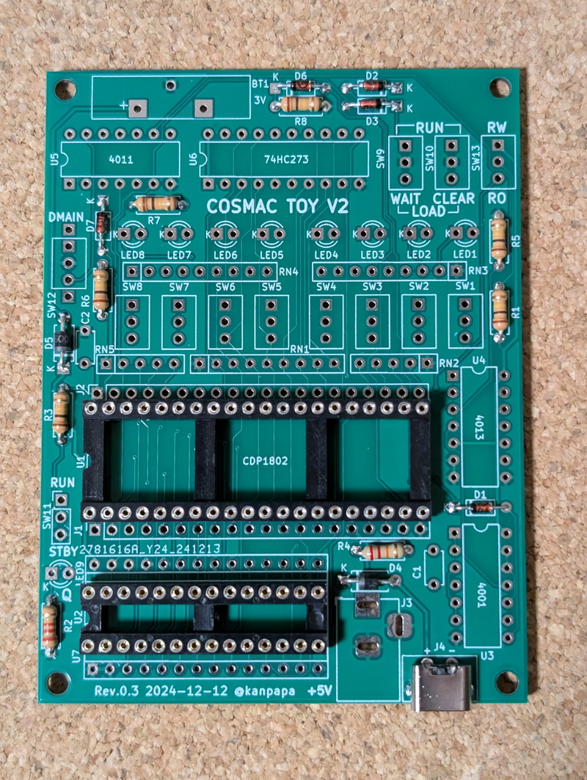
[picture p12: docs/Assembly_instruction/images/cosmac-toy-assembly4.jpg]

1. 平ピンICソケットの取り付け  
U1,U2以外のICには平ピンICソケットをはんだ付けします。向きに注意してください。シルクの切り欠きとソケットの切り欠きを合わせてください。
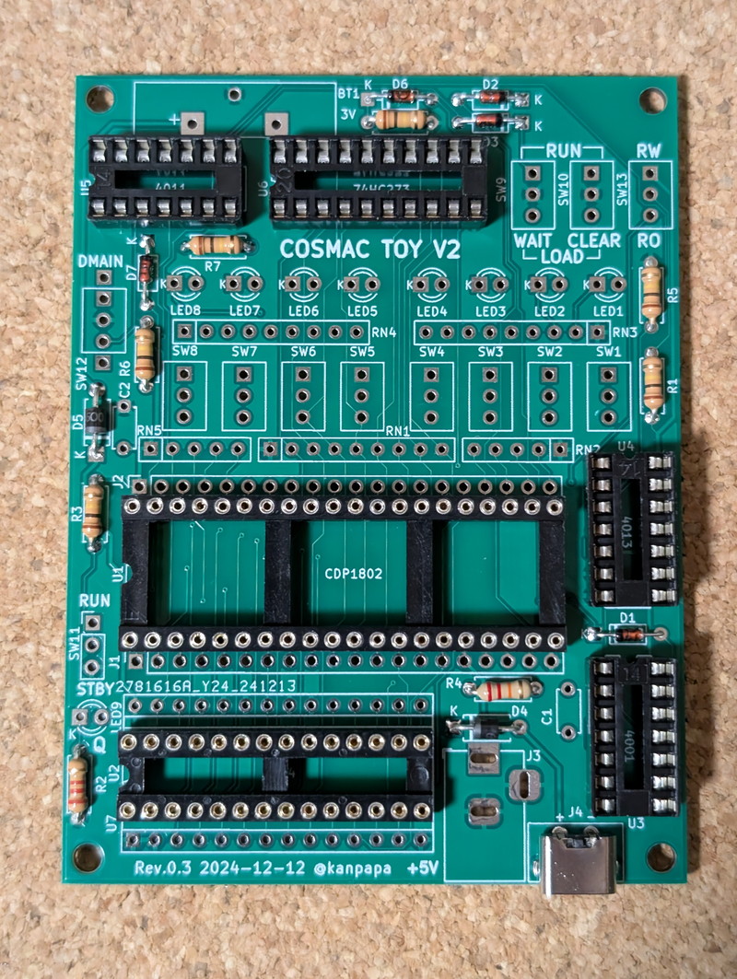
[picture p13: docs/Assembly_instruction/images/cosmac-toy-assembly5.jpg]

1. パーツの高さの確認  
集合抵抗、LED、スライドスイッチの高さを確認して低いものから取り付けていきます。この例ではLED→集合抵抗→スライドスイッチで取り付けてみます。  
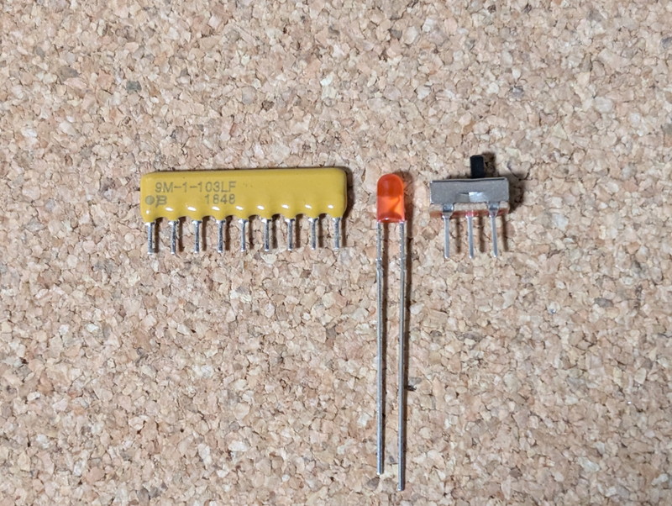
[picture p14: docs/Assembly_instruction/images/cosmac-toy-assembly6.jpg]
 
1. LEDの取り付け  
極性がありますので注意してください。短い足がカソードですので、Kのマークに合わせてはんだ付けしてください。 
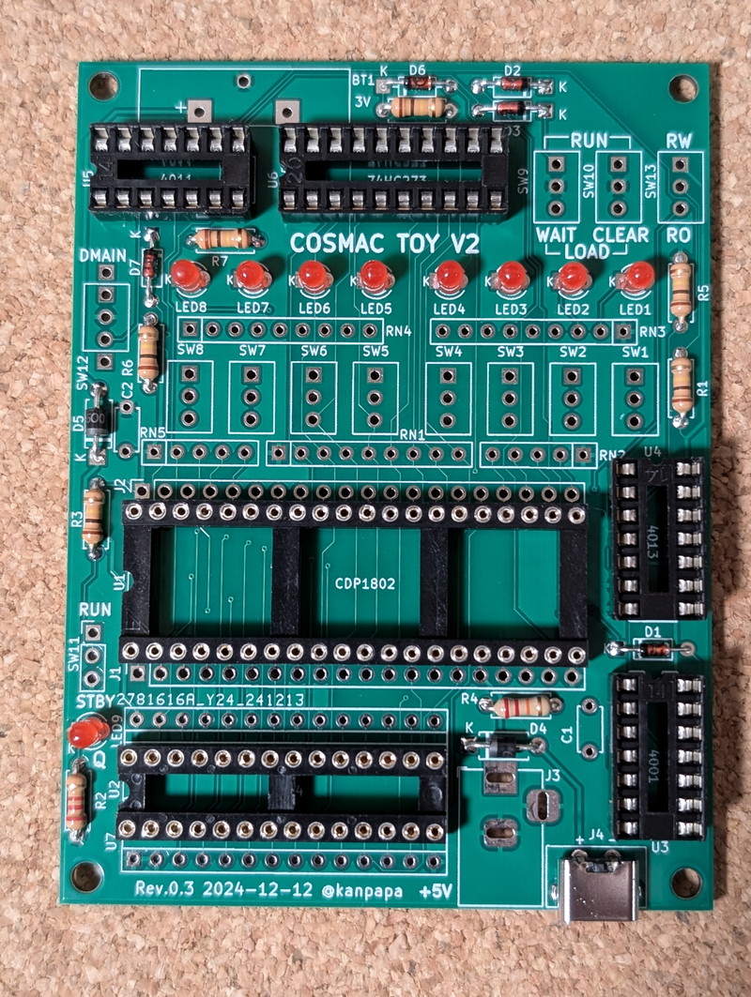
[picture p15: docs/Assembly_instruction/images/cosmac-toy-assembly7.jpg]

1. 集合抵抗の取り付け  
RN1は8素子100KΩ、RN2,RN5は4素子100KΩ、RN3は8素子2.2KΩ、RN4は8素子10KΩです。集合抵抗は向きがあります。パッケージに共通ピンを示す点が書かれていますので、基板のシルクの共通ピンに合わせてください。  
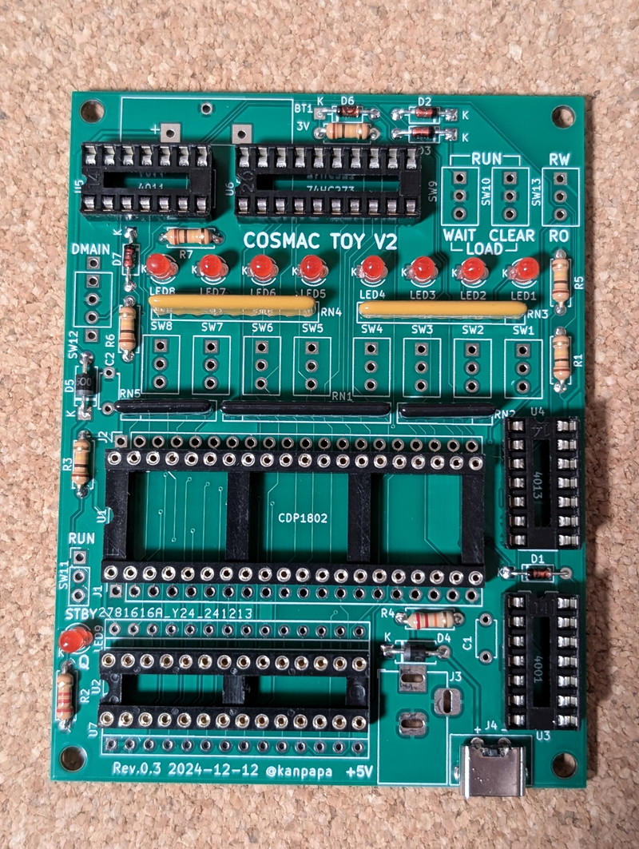
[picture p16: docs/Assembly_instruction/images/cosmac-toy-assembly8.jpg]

1. スライドスイッチの取り付け  
スライドスイッチをはんだ付けします。
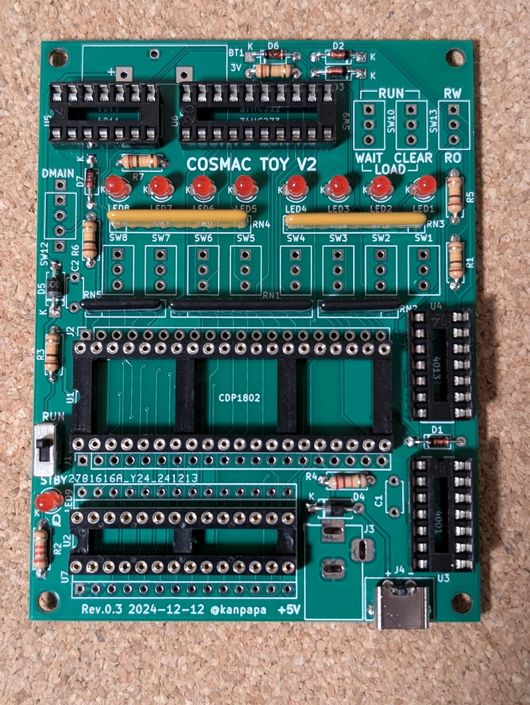
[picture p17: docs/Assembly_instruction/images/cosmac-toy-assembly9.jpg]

1. トグルスイッチの向きを合わせる  
トグルスイッチをはんだ付けする前にスイッチの向きを合わせておきます。この例では写真のように定格が書かれている面を見えるようにして、スイッチを下向きに合わせておきます。向きを合わせておくと実装後にきれいに見えます。
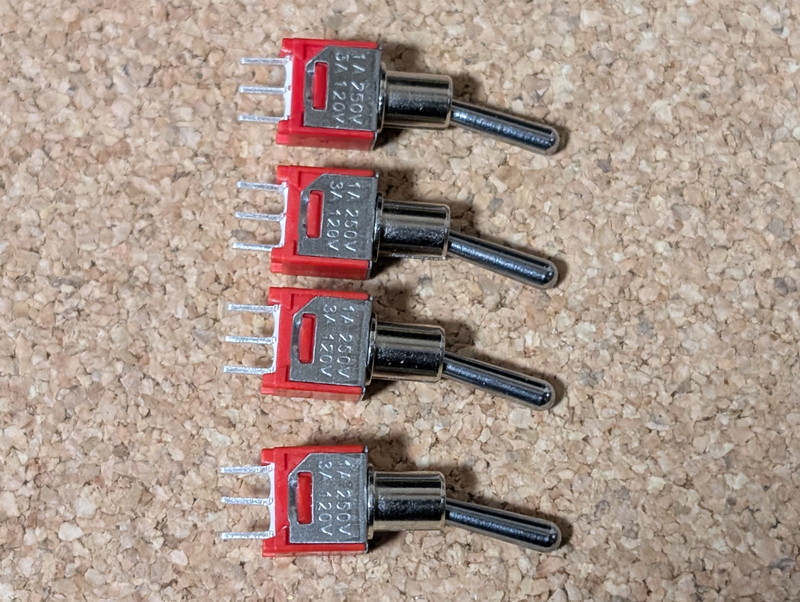
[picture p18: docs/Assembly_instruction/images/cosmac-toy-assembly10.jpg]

1. モード設定トグルスイッチの仮止め  
まずは右上の３つのモード設定トグルスイッチを取り付けます。写真のように取り付けていきます。ここで１つのピンだけはんだ付けして仮止めしておきます。  
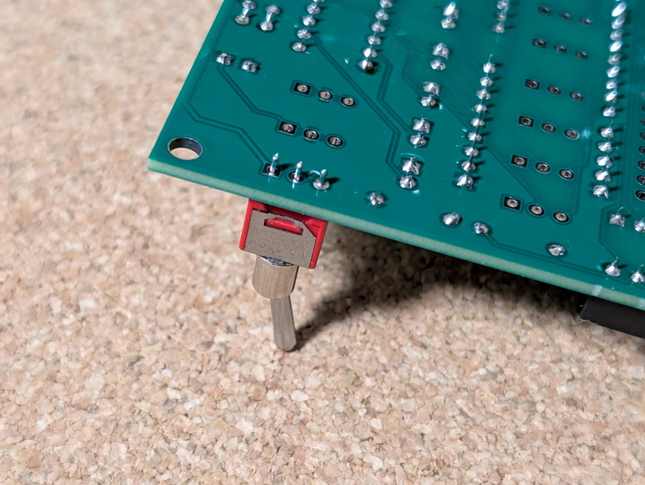
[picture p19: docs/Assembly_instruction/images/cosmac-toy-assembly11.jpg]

1. モード設定トグルスイッチの位置の調整  
仮止めの状態では斜めに取り付けられていることが多いので、正しい位置になるように縦、横から見ながら仮止めしている箇所にはんだコテを当てながらトグルスイッチの位置を調整します。基板面とトグルスイッチの底面がぴったり接触するように上から軽く押し付けるようにしてみてください。  
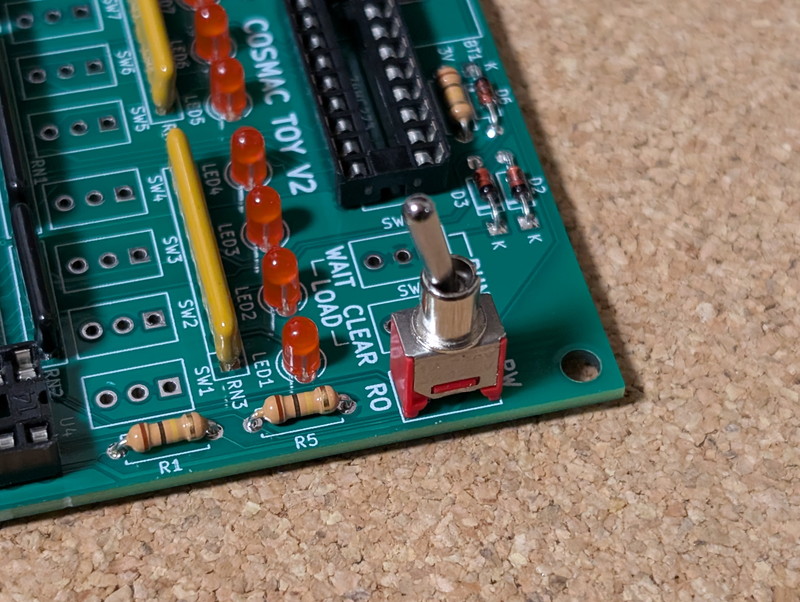
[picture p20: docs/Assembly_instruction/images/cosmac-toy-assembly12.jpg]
 
1. 残りのモード設定トグルスイッチの仮止め  
残り２つのモード設定トグルスイッチも１つのピンだけはんだ付けして同様に仮止めし、位置を合わせます。  
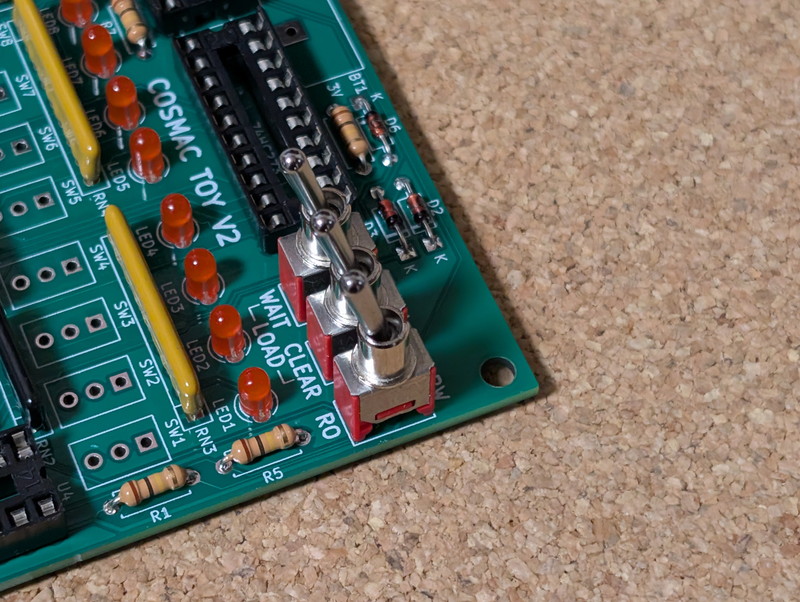
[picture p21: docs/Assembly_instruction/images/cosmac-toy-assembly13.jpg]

1. モード設定トグルスイッチの固定  
３つのトグルスイッチの位置が確定したら、３つのピンをはんだ付けして完全に固定します。力がかかる部分ですのでしっかりはんだ付けしてください。  
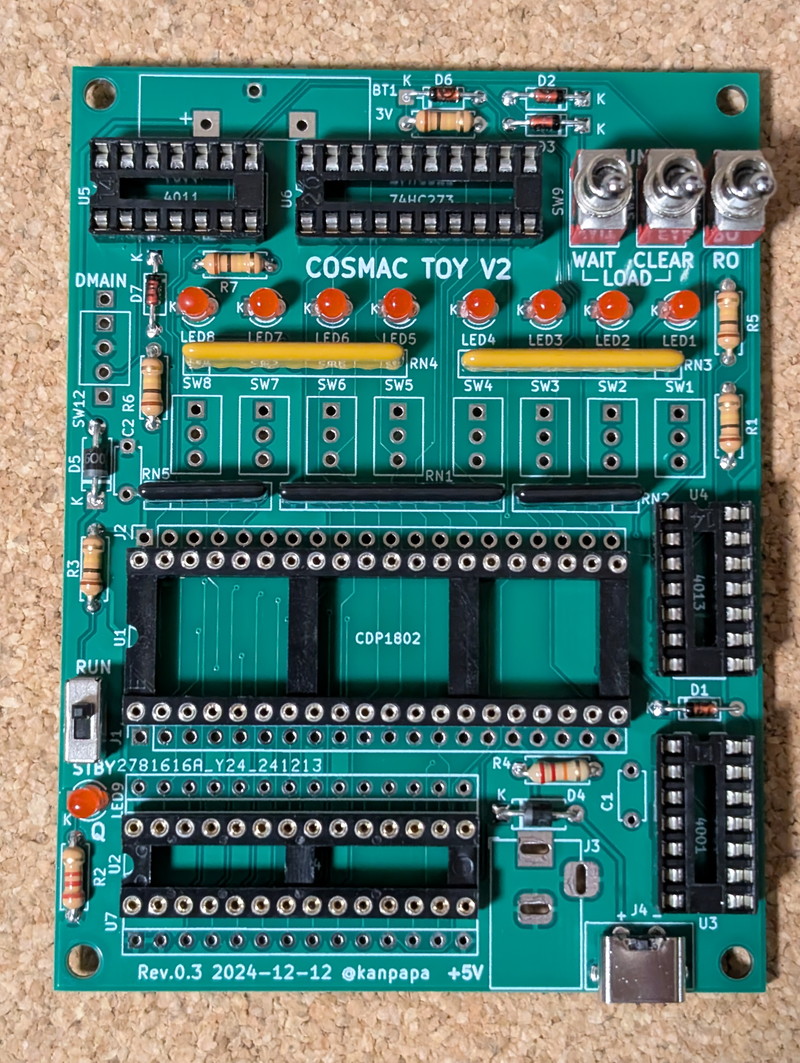
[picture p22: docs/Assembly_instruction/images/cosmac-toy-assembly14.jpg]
  
電池ボックス(BT1)を使用する場合はここではんだ付けしてください。 
1. データ入力トグルスイッチの仮止め  
8つのデータ入力トグルスイッチを先ほどのモード設定トグルスイッチの取り付け方法と同じように取り付けていきます。基板がぐらぐらしないように両端から仮止めすると良いです。  
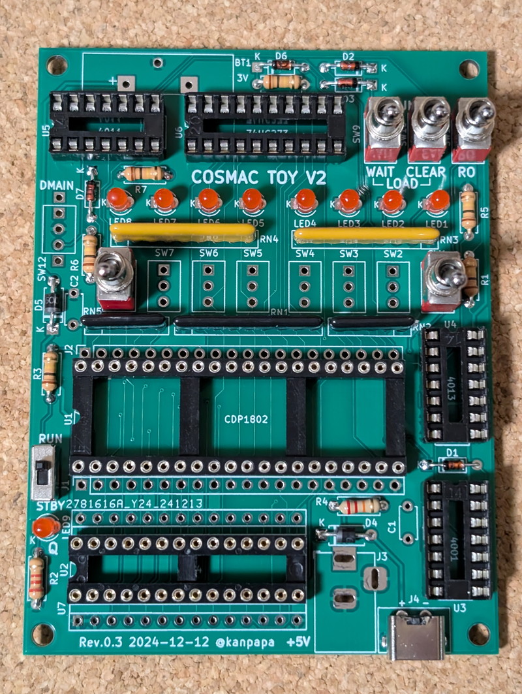
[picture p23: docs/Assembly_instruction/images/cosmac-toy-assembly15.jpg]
 
1. データ入力トグルスイッチの固定  
８つのトグルスイッチの位置が決まったら、３つのピンをはんだ付けして完全に固定します。力がかかる部分ですのでしっかりはんだ付けしてください。  
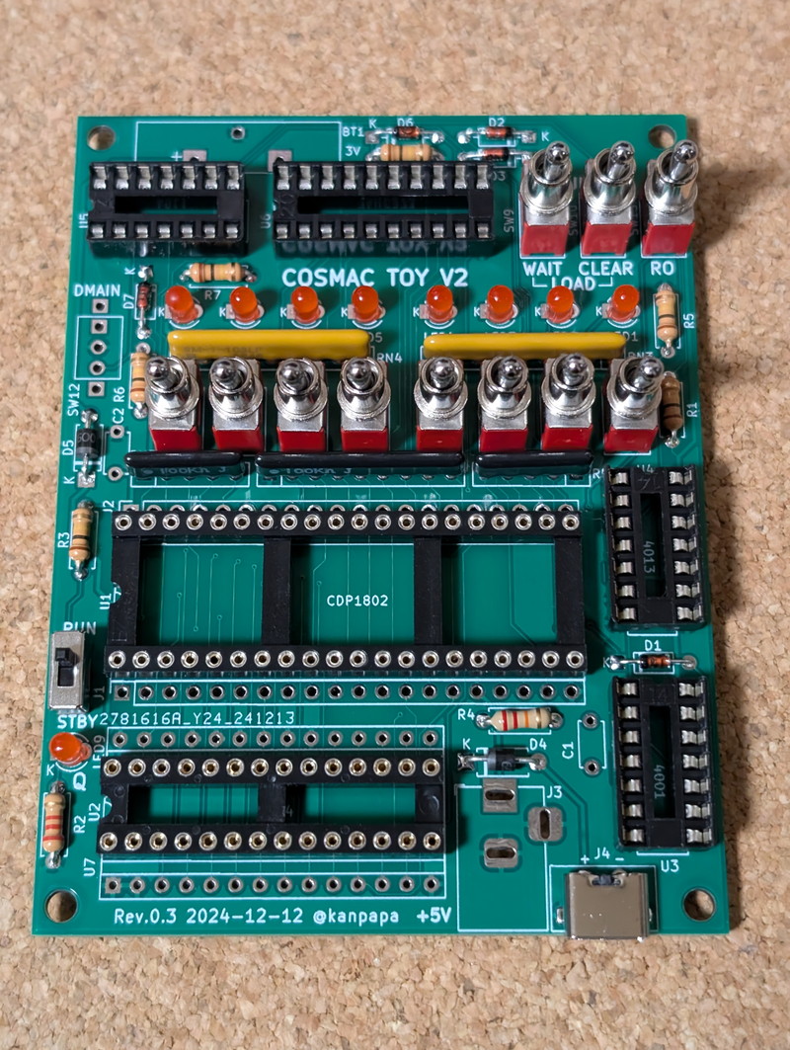
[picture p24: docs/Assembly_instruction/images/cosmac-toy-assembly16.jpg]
 
1. コンデンサのとりつけ  
コンデンサを取り付けます。C1は22P、C2は0.1μF(104)をはんだ付けしてください。
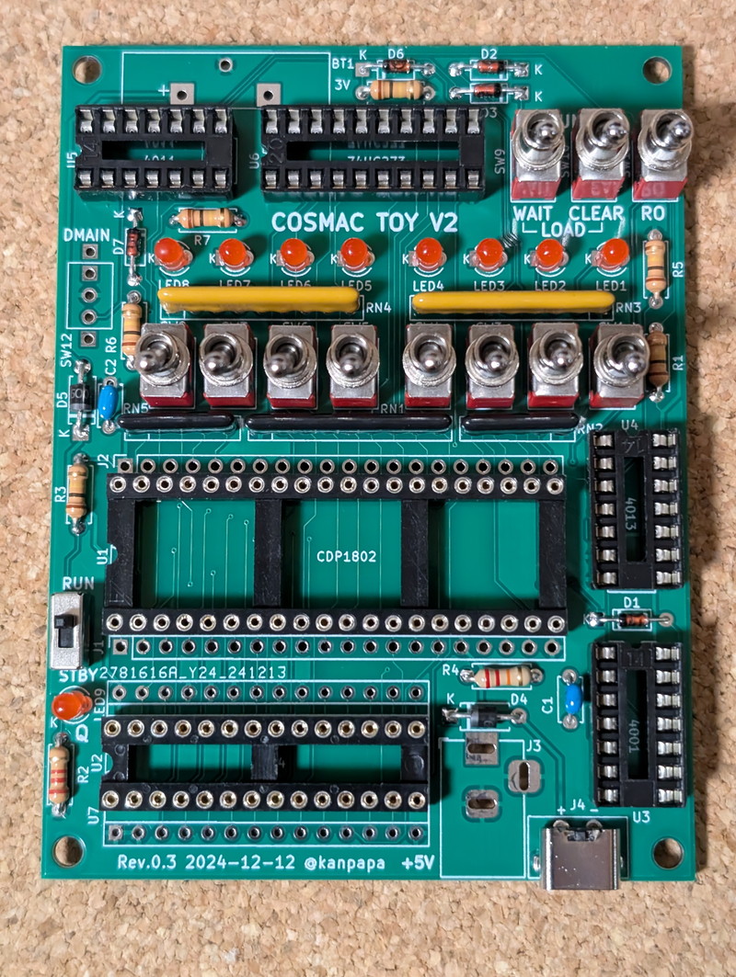
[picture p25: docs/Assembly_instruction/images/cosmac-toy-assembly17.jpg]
 
1. プッシュスイッチの取り付け  
プッシュスイッチは取り付け枠がありますので、正しい位置に固定しやすいです。１ピンだけ仮止めをして問題なければ残りのピンをはんだ付けして固定してください。
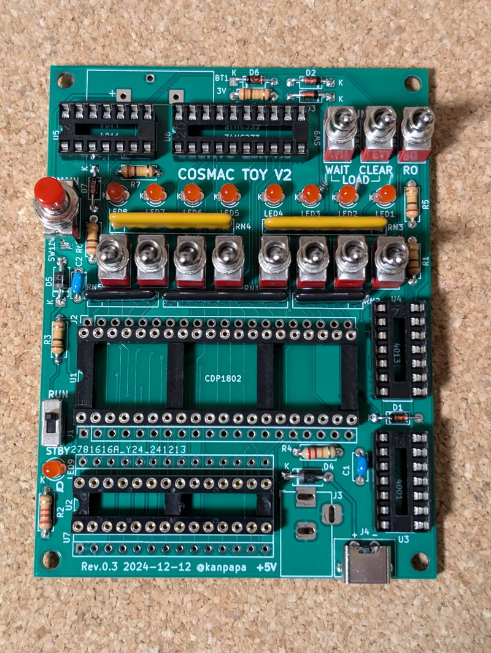
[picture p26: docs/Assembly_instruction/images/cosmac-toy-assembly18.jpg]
 
1. DCジャックの取り付け  
DCジャックを使用する場合はここではんだ付けしてください。
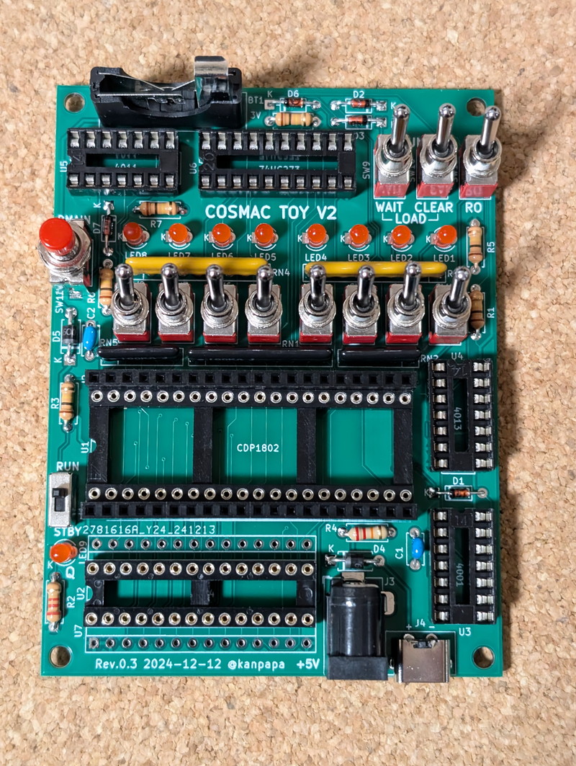
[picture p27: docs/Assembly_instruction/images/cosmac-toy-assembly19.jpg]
 
1. 実装ミスがないかを確認  
以下の点を確認してください。   
    - [ ] 部品面：部品の取り付け忘れがないか。
    - [ ] 部品面：CPU、ロジックIC、ダイオード等の向きは正しいか
    - [ ] 部品面：抵抗の値、コンデンサの値、集合抵抗の値は正しいか  
    - [ ] はんだ面：はんだ付けを忘れているところはないか
    - [ ] はんだ面：はんだでブリッジしているところはないか  
1. 電源ラインの確認  
DCジャックまたはUSB-C電源を接続し、CPUやロジックICの電源ピンに正しく5V電源が供給されているかをテスターで確認することをおすすめします。
1. CPUとロジックICの取り付け  
CPUとロジックICを取り付けます。型番と切り欠きの向きを正しく合わせ、ピンが曲がらないように慎重に取り付けてください。
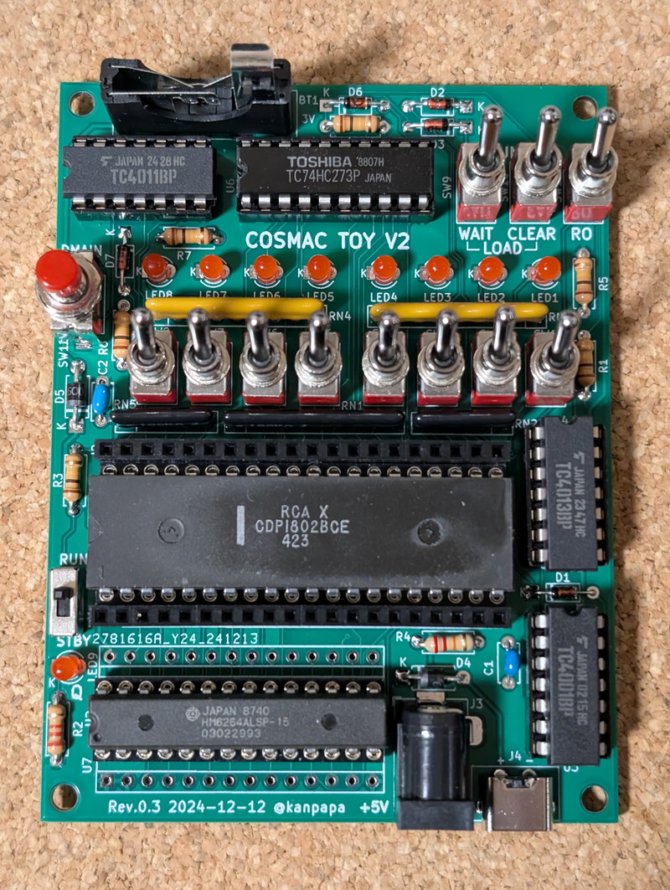
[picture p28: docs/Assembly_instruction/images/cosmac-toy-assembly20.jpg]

1. 動作確認  
DCジャックもしくはUSB-C電源を接続し、動作確認を行います。電源を投入したら変な臭いがしないか、熱くなっているCPUやICが無いかを指で触って確認します。異常があった場合はすぐ電源を切り、実装の再確認を行ってください。  
問題がなさそうであれば、サンプルプログラム [01_osc1](/programs/01_osc1/README.md)の４バイトのプログラムをトグルスイッチで入力し、実行してみてください。Q-LEDが点灯すれば正しく動作しています。お疲れさまでした。 
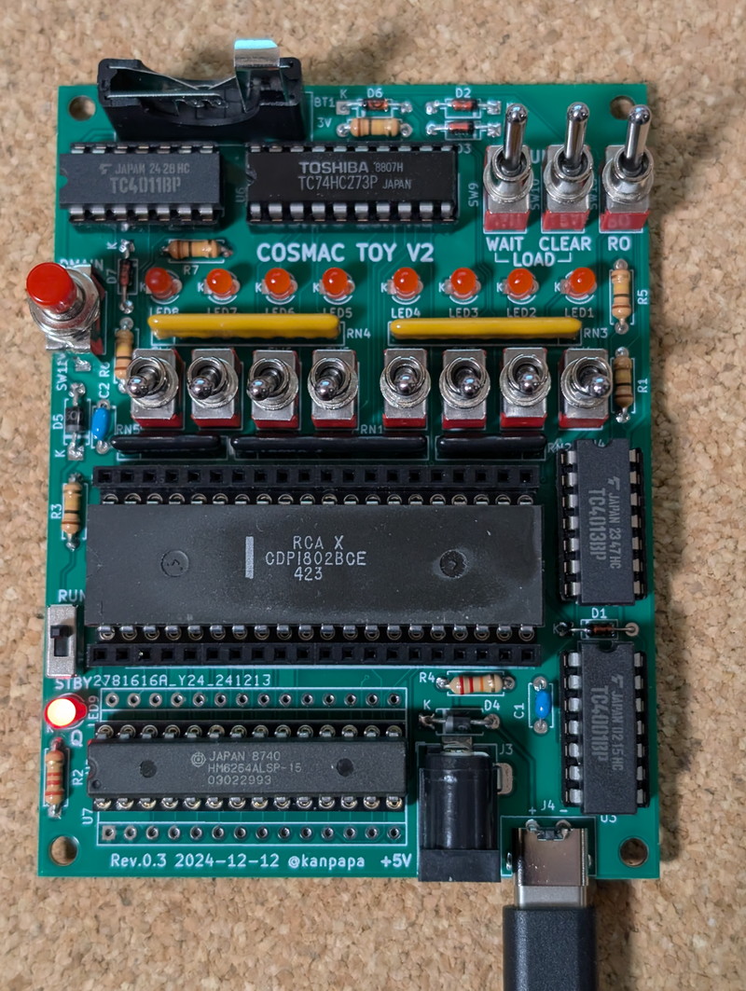
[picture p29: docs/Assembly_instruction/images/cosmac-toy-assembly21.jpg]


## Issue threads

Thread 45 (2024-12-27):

DCジャックの取り付け位置の見直し

kanpapa, 2024-12-27:
300milのS-RAMを使用した場合、DCジャックが邪魔でS-RAMの取り外しが行いにくい。
一度完成してしまえばS-RAMを取り外す必要は無いのですが、いろいろ実験されるかたにとっては不便かもしれない。
現在の基板のレイアウト的に調整できる余地は無いかもですが、次版の検討課題としてissueにあげておきます。

kanpapa, 2024-12-27:
Rev.0.3でUSB−C電源のみの使用でDCジャックを取り付けなければ支障は無い。

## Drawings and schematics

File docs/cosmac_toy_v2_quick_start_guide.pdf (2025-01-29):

# COSMAC Toy V2 Quick start guide

## 入力するプログラム

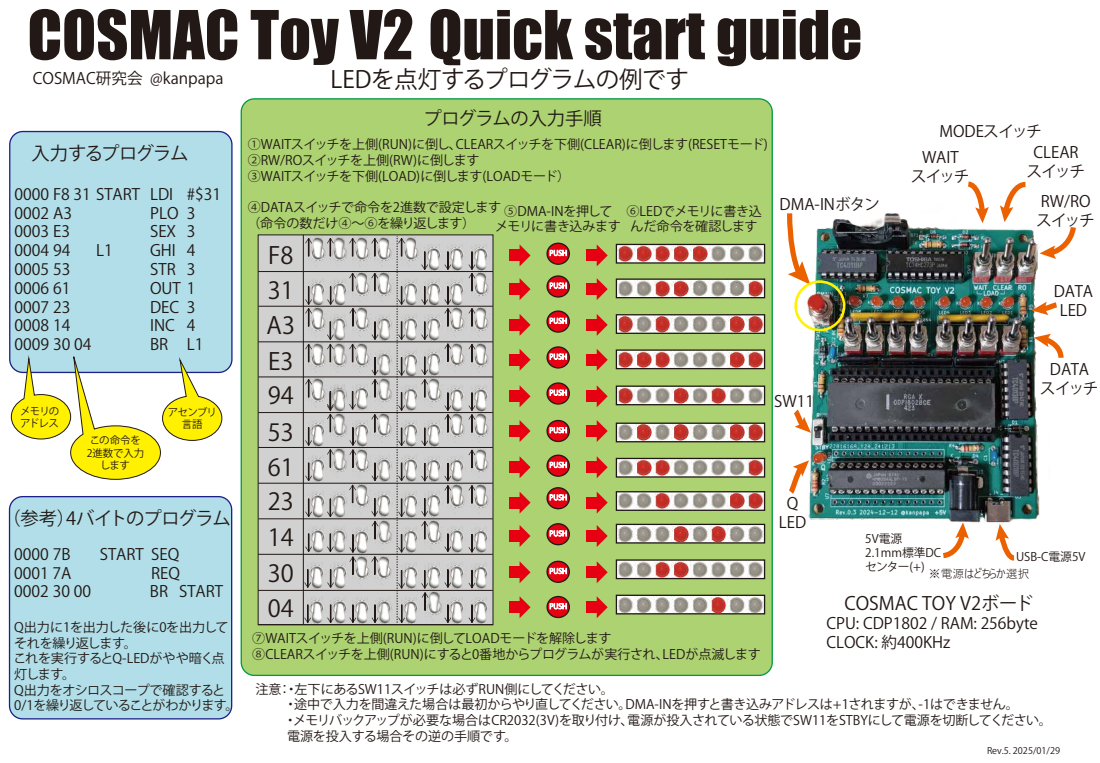
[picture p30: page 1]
COSMAC研究会 @kanpapa; 0000 F8 31 START LDI #$31; PLO 3; SEX 3; GHI 4; STR 3; OUT 1; DEC 3; INC 4; プログラムの入力手順; COSMAC TOY V2ボード; ①WAITスイッチを上側(RUN)に倒し、CLEARスイッチを下側(CLEAR)に倒します(RESETモード) ②RW/ROスイッチを上側(RW)に倒します ③WAITスイッチを下側(LOAD)に倒します(LOADモード） ④DATAスイッチで命令を2進数で設定します （命令の数だけ④～⑥を繰り返します）; ⑦WAITスイッチを上側(RUN)に倒してLOADモードを解除します ⑧CLEARスイッチを上側(RUN)にすると0番地からプログラムが実行され、LEDが点滅します; ⑤DMA-INを押して メモリに書き込みます; ⑥LEDでメモリに書き込 んだ命令を確認します; RW/RO スイッチ; MODEスイッチ; DATA LED; DMA-INボタン; DATA スイッチ; PUSH; メモリの アドレス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

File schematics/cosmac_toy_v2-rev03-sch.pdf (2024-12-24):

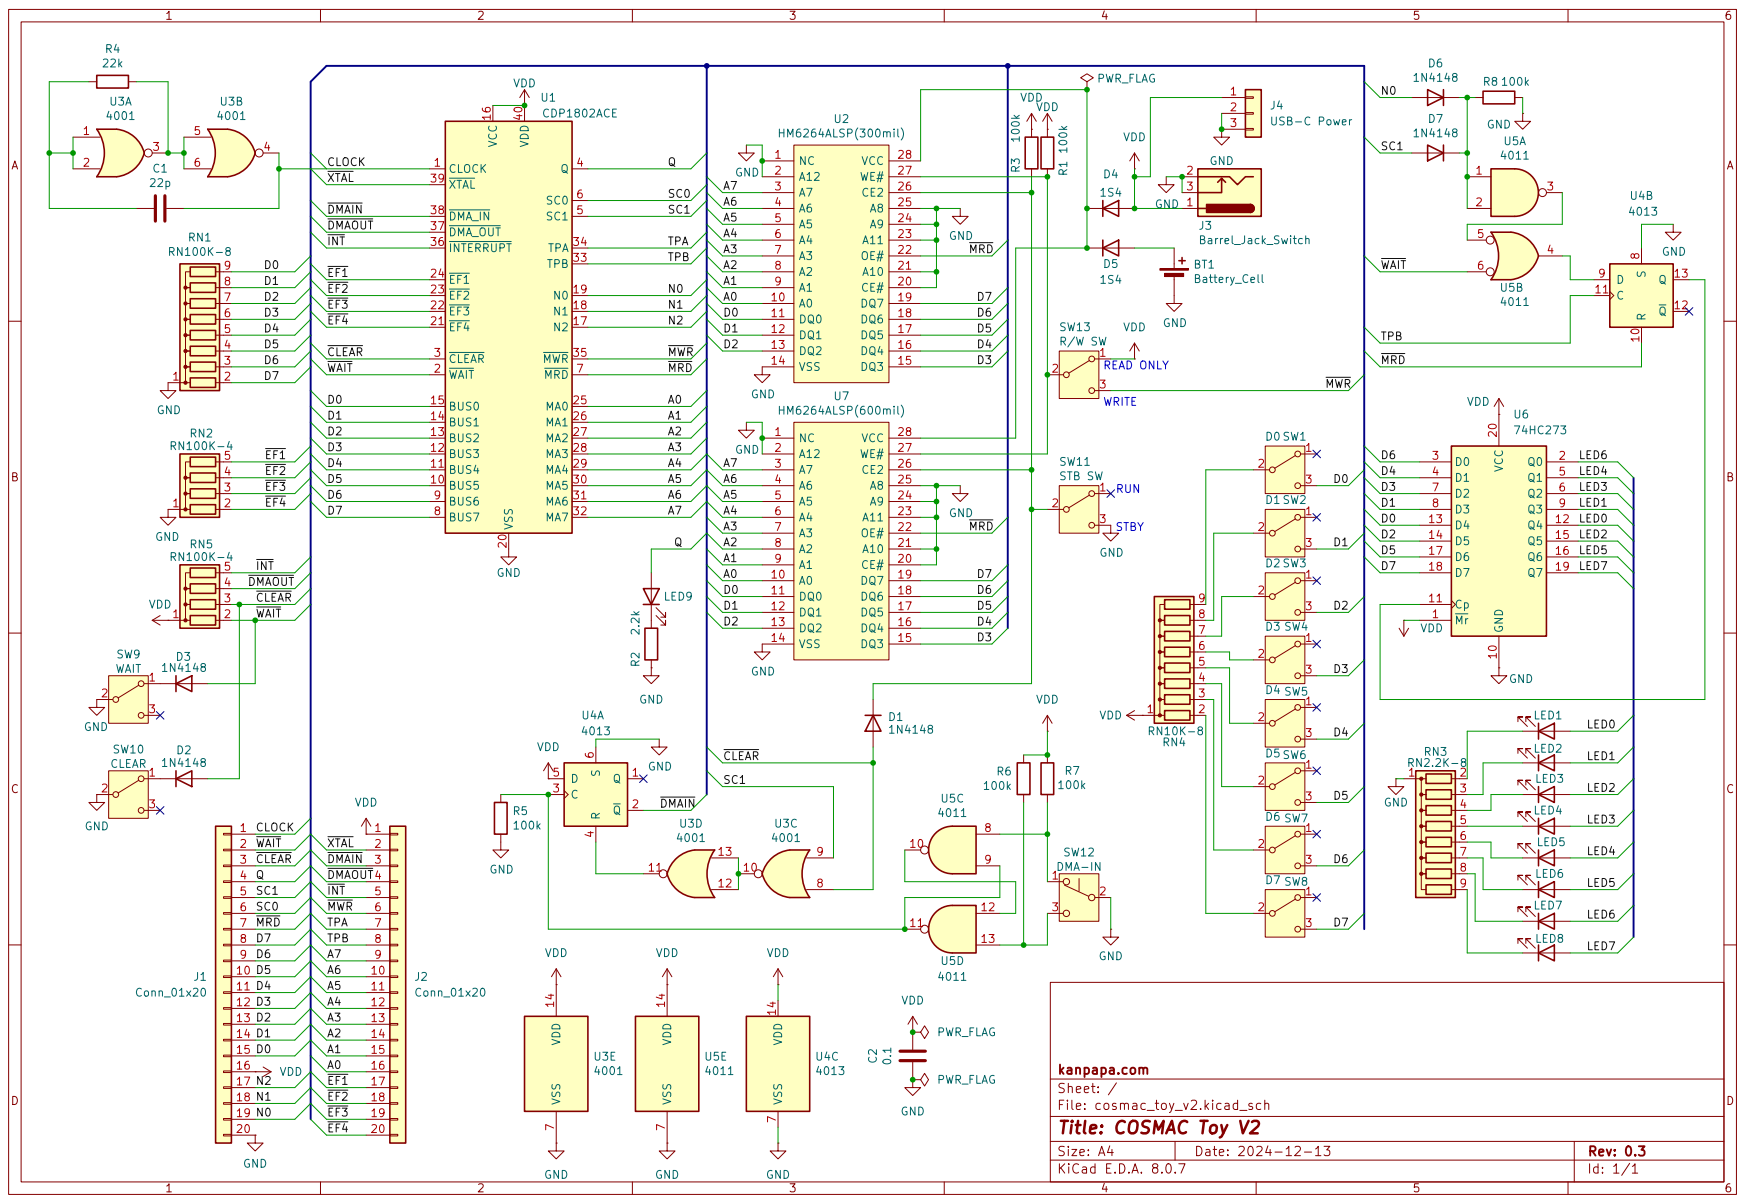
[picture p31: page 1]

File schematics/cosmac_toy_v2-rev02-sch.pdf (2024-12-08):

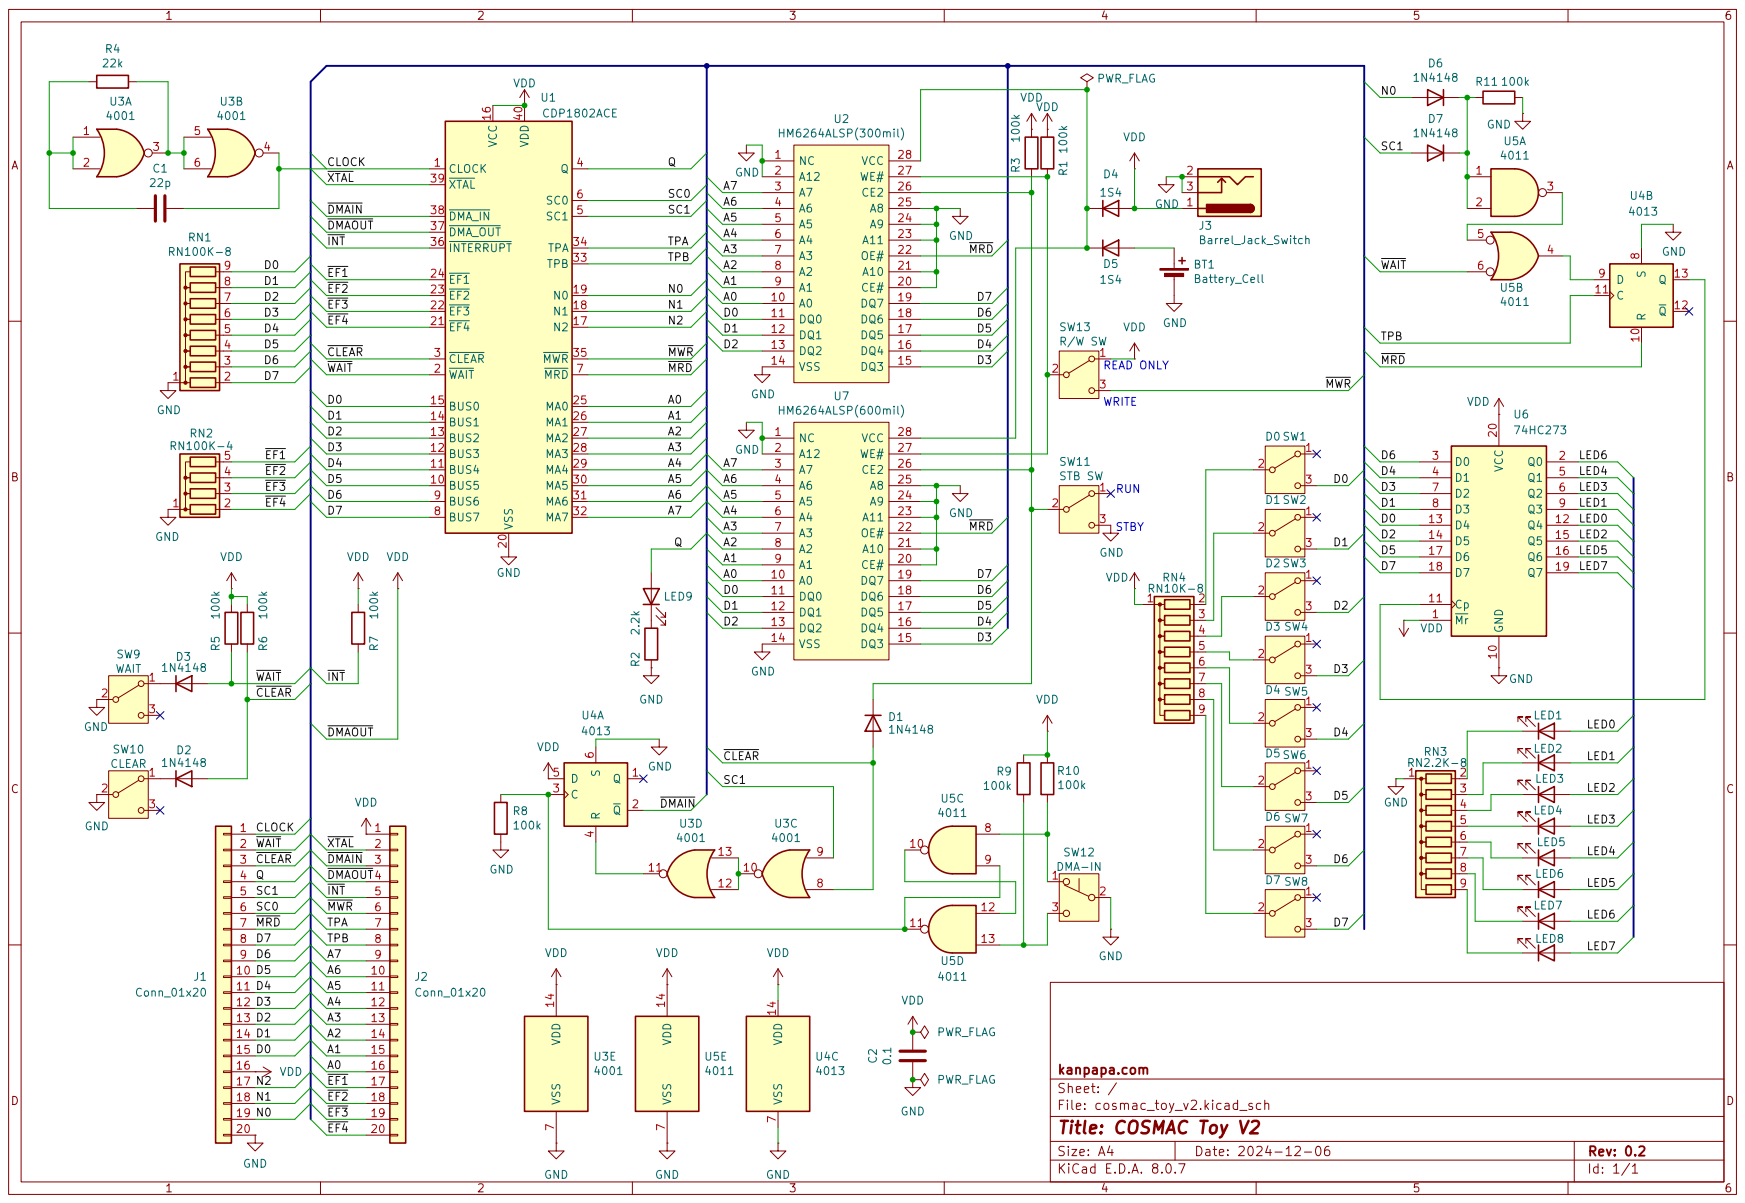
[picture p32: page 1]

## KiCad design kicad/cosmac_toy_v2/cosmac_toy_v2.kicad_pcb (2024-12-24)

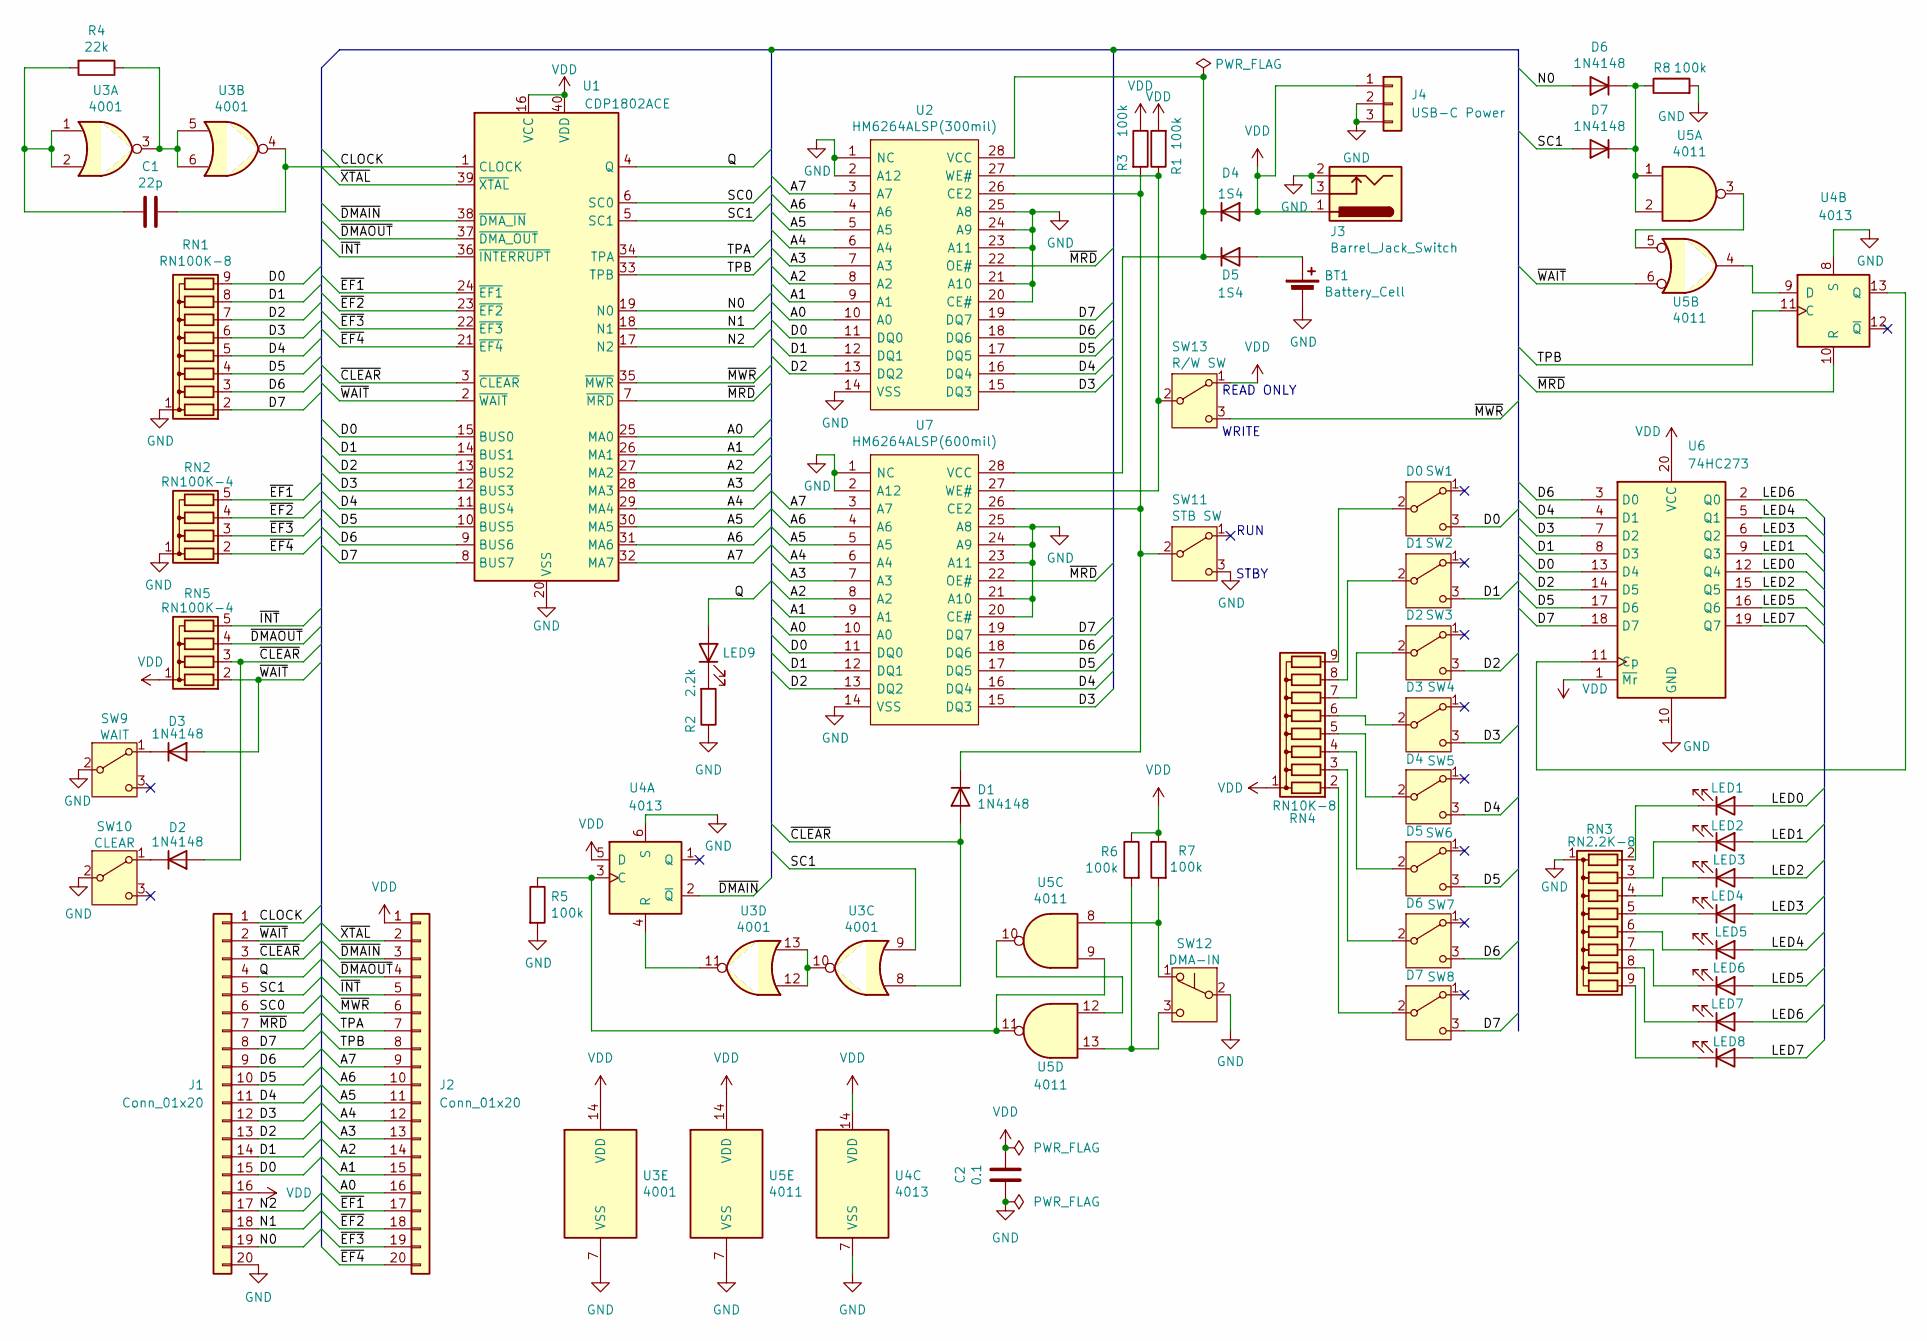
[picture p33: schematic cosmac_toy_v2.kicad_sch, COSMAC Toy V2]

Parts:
BT1: Battery_Cell; CH243-2032CF
C1: 22p; C_Disc_D4.7mm_W2.5mm_P5.00mm
C2: 0.1; C_Disc_D4.7mm_W2.5mm_P5.00mm
D1, D2, D3, D6, D7: 1N4148; D_DO-35_SOD27_P7.62mm_Horizontal
D4, D5: 1S4; D_A-405_P7.62mm_Horizontal
J1, J2: Conn_01x20; PinSocket_1x20_P2.54mm_Vertical
J3: Barrel_Jack_Switch; BarrelJack_Horizontal
J4: USB-C Power; A295-CTRPB-1
LED1, LED2, LED3, LED4, LED5, LED6, LED7, LED8: DATA_LED; LED_D3.0mm
LED9: Q; LED_D3.0mm
R1, R3, R5, R6, R7, R8: 100k; R_Axial_DIN0207_L6.3mm_D2.5mm_P7.62mm_Horizontal
R2: 2.2k; R_Axial_DIN0207_L6.3mm_D2.5mm_P7.62mm_Horizontal
R4: 22k; R_Axial_DIN0207_L6.3mm_D2.5mm_P7.62mm_Horizontal
RN1: RN100K-8; R_Array_SIP9
RN2, RN5: RN100K-4; R_Array_SIP5
RN3: RN2.2K-8; R_Array_SIP9
RN4: RN10K-8; R_Array_SIP9
SW1: D0; SW_Toggle_P2.54mm_Vertical
SW2: D1; SW_Toggle_P2.54mm_Vertical
SW3: D2; SW_Toggle_P2.54mm_Vertical
SW4: D3; SW_Toggle_P2.54mm_Vertical
SW5: D4; SW_Toggle_P2.54mm_Vertical
SW6: D5; SW_Toggle_P2.54mm_Vertical
SW7: D6; SW_Toggle_P2.54mm_Vertical
SW8: D7; SW_Toggle_P2.54mm_Vertical
SW9: WAIT; SW_Toggle_P2.54mm_Vertical
SW10: CLEAR; SW_Toggle_P2.54mm_Vertical
SW11: STB SW; PinHeader_1x03_P2.54mm_Vertical
SW12: DMA-IN; PushSwitch
SW13: R/W SW; SW_Toggle_P2.54mm_Vertical
U1: CDP1802ACE; DIP-40_W15.24mm_Socket
U2: HM6264ALSP(300mil); DIP-28_W7.62mm_Socket
U3: 4001; DIP-14_W7.62mm
U4: 4013; DIP-14_W7.62mm
U5: 4011; DIP-14_W7.62mm
U6: 74HC273; DIP-20_W7.62mm
U7: HM6264ALSP(600mil); DIP-28_W15.24mm_Socket

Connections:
/A0: J2.16, U1.25 (MA0), U2.10 (A0), U7.10 (A0)
/A1: J2.15, U1.26 (MA1), U2.9 (A1), U7.9 (A1)
/A2: J2.14, U1.27 (MA2), U2.8 (A2), U7.8 (A2)
/A3: J2.13, U1.28 (MA3), U2.7 (A3), U7.7 (A3)
/A4: J2.12, U1.29 (MA4), U2.6 (A4), U7.6 (A4)
/A5: J2.11, U1.30 (MA5), U2.5 (A5), U7.5 (A5)
/A6: J2.10, U1.31 (MA6), U2.4 (A6), U7.4 (A6)
/A7: J2.9, U1.32 (MA7), U2.3 (A7), U7.3 (A7)
/CLOCK: C1.2, J1.1, U1.1 (CLOCK), U3.4
/D0: J1.15, RN1.9 (R8), SW1.3 (C), U1.15 (BUS0), U2.11 (DQ0), U6.13 (D4), U7.11 (DQ0)
/D1: J1.14, RN1.8 (R7), SW2.3 (C), U1.14 (BUS1), U2.12 (DQ1), U6.8 (D3), U7.12 (DQ1)
/D2: J1.13, RN1.7 (R6), SW3.3 (C), U1.13 (BUS2), U2.13 (DQ2), U6.14 (D5), U7.13 (DQ2)
/D3: J1.12, RN1.6 (R5), SW4.3 (C), U1.12 (BUS3), U2.15 (DQ3), U6.7 (D2), U7.15 (DQ3)
/D4: J1.11, RN1.5 (R4), SW5.3 (C), U1.11 (BUS4), U2.16 (DQ4), U6.4 (D1), U7.16 (DQ4)
/D5: J1.10, RN1.4 (R3), SW6.3 (C), U1.10 (BUS5), U2.17 (DQ5), U6.17 (D6), U7.17 (DQ5)
/D6: J1.9, RN1.3 (R2), SW7.3 (C), U1.9 (BUS6), U2.18 (DQ6), U6.3 (D0), U7.18 (DQ6)
/D7: J1.8, RN1.2 (R1), SW8.3 (C), U1.8 (BUS7), U2.19 (DQ7), U6.18 (D7), U7.19 (DQ7)
/LED0: LED1.2 (A), U6.12 (Q4)
/LED1: LED2.2 (A), U6.9 (Q3)
/LED2: LED3.2 (A), U6.15 (Q5)
/LED3: LED4.2 (A), U6.6 (Q2)
/LED4: LED5.2 (A), U6.5 (Q1)
/LED5: LED6.2 (A), U6.16 (Q6)
/LED6: LED7.2 (A), U6.2 (Q0)
/LED7: LED8.2 (A), U6.19 (Q7)
/N0: D6.2 (A), J1.19, U1.19 (N0)
/N1: J1.18, U1.18 (N1)
/N2: J1.17, U1.17 (N2)
/Q: J1.4, LED9.2 (A), U1.4 (Q)
/SC0: J1.6, U1.6 (SC0)
/SC1: D7.2 (A), J1.5, U1.5 (SC1), U3.9
/TPA: J2.7, U1.34 (TPA)
/TPB: J2.8, U1.33 (TPB), U4.11 (C)
/~CLEAR: D1.2 (A), D2.2 (A), J1.3, RN5.3 (R2), U1.3 (~CLEAR), U3.8
/~DMAIN: J2.3, U1.38 (~DMA_IN), U4.2 (~Q)
/~DMAOUT: J2.4, RN5.4 (R3), U1.37 (~DMA_OUT)
/~EF1: J2.17, RN2.5 (R4), U1.24 (~EF1)
/~EF2: J2.18, RN2.4 (R3), U1.23 (~EF2)
/~EF3: J2.19, RN2.3 (R2), U1.22 (~EF3)
/~EF4: J2.20, RN2.2 (R1), U1.21 (~EF4)
/~INT: J2.5, RN5.5 (R4), U1.36 (~INTERRUPT)
/~MRD: J1.7, U1.7 (~MRD), U2.22 (OE#), U4.10 (R), U7.22 (OE#)
/~MWR: J2.6, SW13.3 (C), U1.35 (~MWR)
/~WAIT: D3.2 (A), J1.2, RN5.2 (R1), U1.2 (~WAIT), U5.6
/~XTAL: J2.2, U1.39 (~XTAL)
GND: BT1.2 (-), C2.2, J1.20, J3.2, J3.3, J4.2, J4.3, R2.1, R5.2, R8.2, RN1.1 (common), RN2.1 (common), RN3.1 (common), SW9.2 (B), SW10.2 (B), SW11.3 (C), SW12.2 (B), U1.20 (VSS), U2.1 (NC), U2.2 (A12), U2.14 (VSS), U2.20 (CE#), U2.21 (A10), U2.23 (A11), U2.24 (A9), U2.25 (A8), U3.7 (VSS), U4.6 (S), U4.7 (VSS), U4.8 (S), U5.7 (VSS), U6.10 (GND), U7.1 (NC), U7.2 (A12), U7.14 (VSS), U7.20 (CE#), U7.21 (A10), U7.23 (A11), U7.24 (A9), U7.25 (A8)
unnamed: BT1.1 (+), D5.2 (A)
unnamed: C1.1, R4.2, U3.1, U3.2
unnamed: D1.1 (K), R3.2, SW11.2 (B), U2.26 (CE2), U7.26 (CE2)
unnamed: D2.1 (K), SW10.1 (A)
unnamed: D3.1 (K), SW9.1 (A)
unnamed: D4.1 (K), D5.1 (K), U2.28 (VCC), U7.28 (VCC)
unnamed: D6.1 (K), D7.1 (K), R8.1, U5.1, U5.2
unnamed: LED1.1 (K), RN3.2 (R1)
unnamed: LED2.1 (K), RN3.3 (R2)
unnamed: LED3.1 (K), RN3.4 (R3)
unnamed: LED4.1 (K), RN3.5 (R4)
unnamed: LED5.1 (K), RN3.6 (R5)
unnamed: LED6.1 (K), RN3.7 (R6)
unnamed: LED7.1 (K), RN3.8 (R7)
unnamed: LED8.1 (K), RN3.9 (R8)
unnamed: LED9.1 (K), R2.2
unnamed: R4.1, U3.3, U3.5, U3.6
unnamed: RN4.2 (R1), SW8.2 (B)
unnamed: RN4.3 (R2), SW7.2 (B)
unnamed: RN4.4 (R3), SW6.2 (B)
unnamed: RN4.5 (R4), SW5.2 (B)
unnamed: RN4.6 (R5), SW4.2 (B)
unnamed: RN4.7 (R6), SW3.2 (B)
unnamed: RN4.8 (R7), SW2.2 (B)
unnamed: RN4.9 (R8), SW1.2 (B)
unnamed: R7.2, SW12.1 (A), U5.8
unnamed: R6.2, SW12.3 (C), U5.13
unnamed: R1.1, SW13.2 (B), U2.27 (WE#), U7.27 (WE#)
unnamed: U3.10, U3.12, U3.13
unnamed: R5.1, U4.3 (C), U5.9, U5.11
unnamed: U3.11, U4.4 (R)
unnamed: U4.9 (D), U5.4
unnamed: U4.13 (Q), U6.11 (Cp)
unnamed: U5.3, U5.5
unnamed: U5.10, U5.12
VDD: C2.1, D4.2 (A), J1.16, J2.1, J3.1, J4.1, R1.2, R3.1, R6.1, R7.1, RN4.1 (common), RN5.1 (common), SW13.1 (A), U1.16 (VCC), U1.40 (VDD), U3.14 (VDD), U4.5 (D), U4.14 (VDD), U5.14 (VDD), U6.1 (~Mr), U6.20 (VCC)

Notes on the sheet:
RUN
STBY
WRITE
READ ONLY

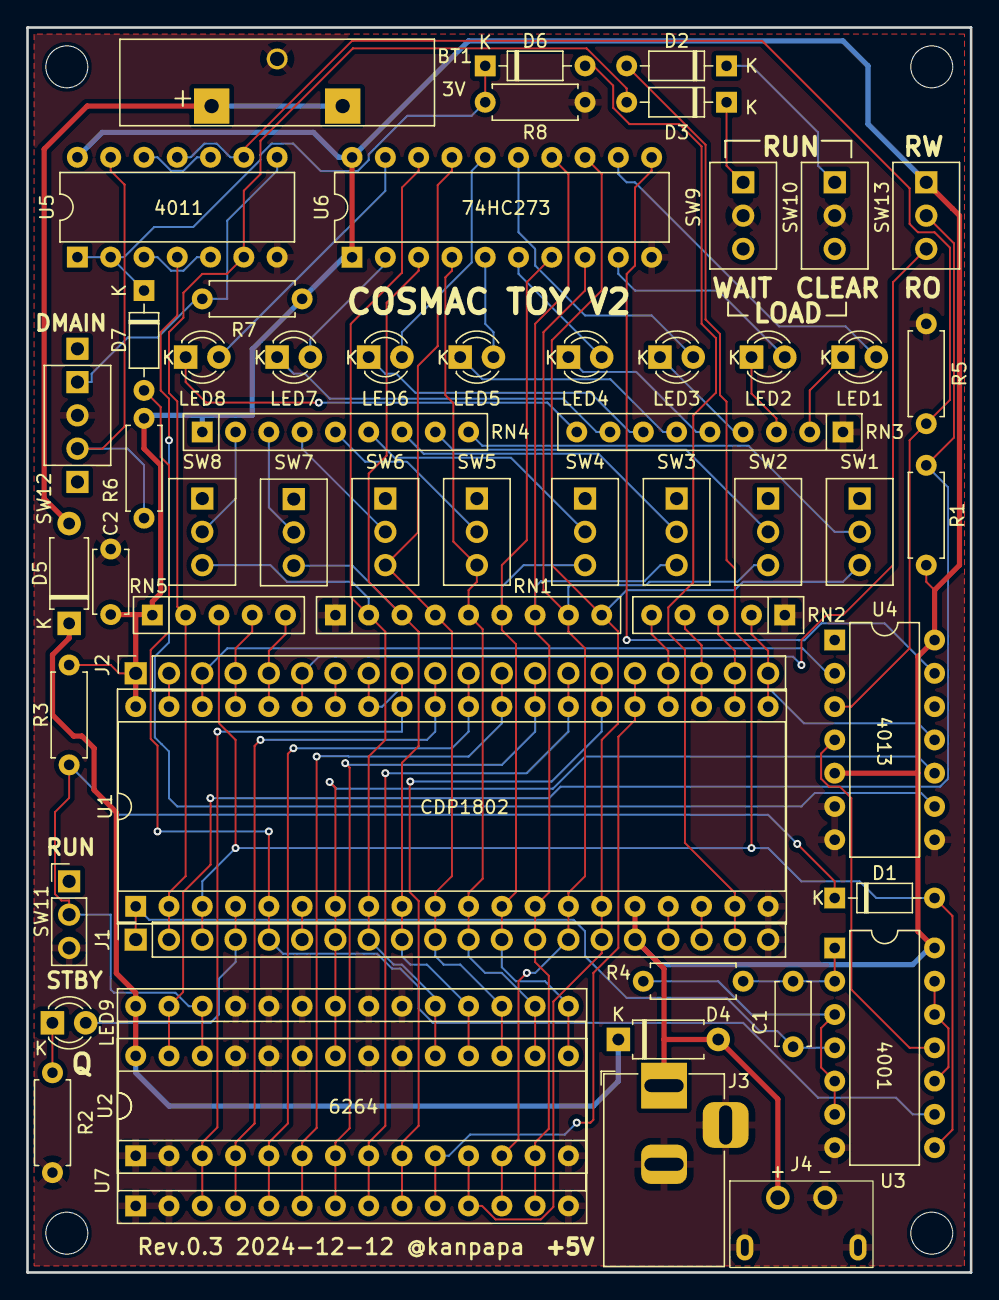
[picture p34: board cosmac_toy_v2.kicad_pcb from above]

Board: 2 copper layers, 72.0 x 95.0 mm, 60 parts (0 on the bottom side), 82 nets.

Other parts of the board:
MH1, MH2, MH3, MH4: MountingHole_3.2mm_M3

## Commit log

2024-12-08 使用方法の書き方を修正
2024-12-08 メモリ書き込み禁止スイッチについて補足を追加
2024-12-08 回路図を追加
2024-12-08 README.mdの章立てを修正
2024-12-08 BOMの追加とファイル名見直し
    [cosmac_toy_v2-rev02-bom.csv]
2024-12-08 推敲結果を反映
2024-12-08 行間調整
2024-12-08 操作方法の記載内容を見直し
2024-12-10 サンプルプログラムOSC1で実行中の写真を追加
2024-12-10 counter1, counter2 にファイル名を変更し、画像を追加
2024-12-10 改行を修正
2024-12-10 再度改行を修正
2024-12-10 osc1のREDAMEに使用する命令を追記
2024-12-10 URLを修正
2024-12-10 サンプルプログラムの加算結果の写真を追加
2024-12-10 sw1とblink1に動画を追加
2024-12-10 文面の調整
2024-12-10 Added KICad project data and gerber data
    [cosmac_toy_v2.kicad_pcb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]
2024-12-10 配布不要なファイルの削除
2024-12-11 参考入手先の記載漏れがあったので修正
    [cosmac_toy_v2-rev02-bom.csv]
2024-12-11 メモリバックアップ状態〜通常状態への切り替え手順の誤記を修正
2024-12-23 Added KiCad project Rev.0.3
    [cosmac_toy_v2.kicad_pcb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]
2024-12-24 Added BOM for Rev.0.3
    [cosmac_toy_v2-rev03-bom.csv]
2024-12-24 KiCad ProjectのREADMEを追加
2024-12-24 Rev.0.3の回路図を追加
    [cosmac_toy_v2-rev03.csv]
2024-12-24 Rev.0.3 の回路図を追加
2024-12-24 不要なファイルを削除
    [cosmac_toy_v2-rev03.csv]
2024-12-24 Rev.0.1の写真を追加
2024-12-24 リチウム電池の取り扱いについて注意事項を追記しました
2024-12-24 Rev.0.3の回路図を修正
2024-12-26 Added POV sample program
2024-12-27 使用するLEDによってはRN3を調整する必要があることを明記しました。
2024-12-27 LEDを10個入りパックの型番に変更
    [cosmac_toy_v2-rev03-bom.csv]
2024-12-27 コメントを追加
    [cosmac_toy_v2-rev03-bom.csv]
2024-12-27 同じ型番のものは統合
    [cosmac_toy_v2-rev03-bom.csv]
2024-12-27 単価を修正
    [cosmac_toy_v2-rev03-bom.csv]
2024-12-27 BOMで同一型番のものは集約
    [cosmac_toy_v2-rev03-bom.csv]
2024-12-27 単価のミスを修正
    [cosmac_toy_v2-rev03-bom.csv]
2024-12-28 合計の誤りを修正
    [cosmac_toy_v2-rev03-bom.csv]
2024-12-28 入手先の記載漏れを修正
    [cosmac_toy_v2-rev03-bom.csv]
2024-12-28 電源用USB−Cコネクタが入荷未定となっているので代替品を追記
    [cosmac_toy_v2-rev03-bom.csv]
2024-12-31 Added source and assemble list
2024-12-31 EF3が負論理であることを回路図に明記
2025-01-02 Added Assembly instructions
2025-01-02 Updated assembly readme
2025-01-02 Updated Assembly instructions
2025-01-29 組み立て手順書に回路図と部品表をリンク
2025-02-06 組み立て手順書にパーツの定格等を追加
